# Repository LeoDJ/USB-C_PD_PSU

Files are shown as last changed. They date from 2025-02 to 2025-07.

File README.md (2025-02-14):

# USB-C PD PSU
> [!WARNING]
> This is a WIP project. It is not yet recommended to reproduce it in its current state. 

A bidirectional buck-boost DC-DC converter with the following features:
- 240W USB PD EPR (48V 5A)*
- 5-60V input
- 3.3-60V output
- 20A maximum current (theoretically, depending on the thermal solution)
- Constant-current control
- `TI BQ25758A` DC-DC controller
- `WCH CH32X035` as the USB Type-C PD controller (hopefully*)
- Protection of CC and USB data lines up to 63V (`TI TPD4S480`)
- Rough mechanical compatibility with [FranzImsch's parkside-adapter](https://github.com/FranzImsch/parkside-adapter)
- A separate-ish "HMI"/"UI" part of the PCB containing:
  - `XT30` connectors for power in/output
  - 1.47" IPS display
  - Encoder + button controls
  - 1.27mm 2x06 expansion header with a few GPIOs / RS485 for potentially communicating with BMS's, etc.
  - A second `CH32X035`
  - Separable via rotary cutting tool (no mouse bites, because of the high current connections to the XT30 plugs and to not fall into the JLCPCB "two designs" price tier)
- 50x50mm PCB size (50x23mm without the "UI" part)

\* depending on the yet-to-be-written PD firmware (and an actually functioning DC-DC converter layout :P)

You can follow the [Mastodon thread](https://chaos.social/@LeoDJ/113874922536756547) for more up-to-date progress on this project.

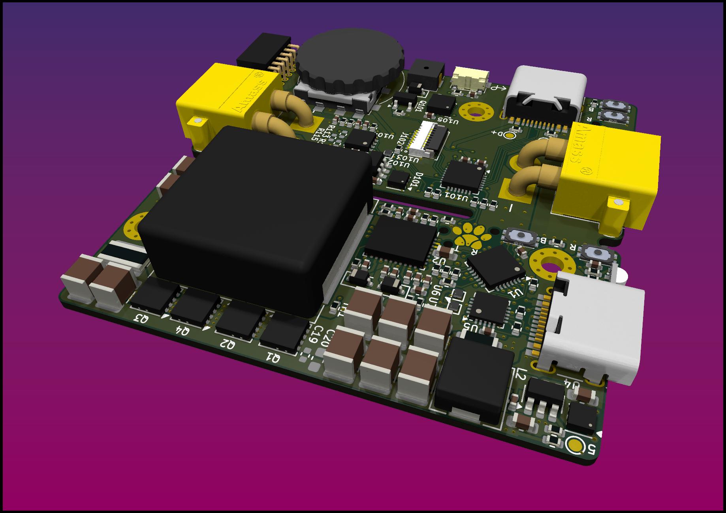
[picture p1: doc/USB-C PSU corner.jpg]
&nbsp;
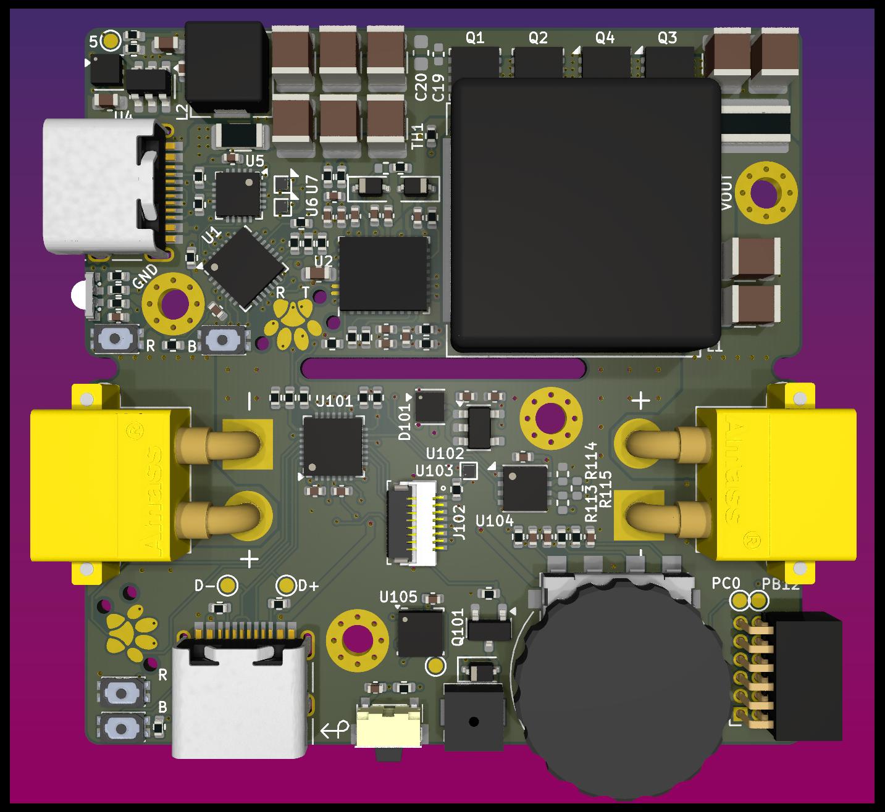
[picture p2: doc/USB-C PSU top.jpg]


## Hardware
The v1.0 PCB is designed in 8 layers, but 6 would probably suffice too. Thus inner layers 3 and 4 were designed as containing only more GND / power copper pours and can probably be left out, only leading to a reduction of a combined copper thickness from 175µm to 140µm.

### JLCPCB Ordering Settings
- Default, except:
- PCB Thickness: `1.0mm`
- Mark on PCB: `Remove Mark`
- Stencil:
  - (Stencil Side: `Top`)
  - Customized Size: `Yes - 200 x 200mm` (saves on shipping cost)

## References
- ESD-Paw symbol: [diminDDL](https://github.com/diminDDL) ([Source](https://github.com/Caraffa-git/PCB-Art/tree/main/SVG/ESD-paw))
- Paw-shaped Tag-Connect pawprint: [Paw-Connect](https://github.com/LeoDJ/Paw-Connect)

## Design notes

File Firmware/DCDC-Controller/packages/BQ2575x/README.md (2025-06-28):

# BQ2575x Library

WIP.  
Aims to be a generic library for the Texas Instruments BQ2575x-series charger / DCDC controller ICs.

Currently supported*:
- BQ25756
- BQ25758A

\* once done

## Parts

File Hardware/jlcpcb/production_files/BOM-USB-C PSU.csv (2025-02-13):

Comment | Designator | Footprint | LCSC
LIS3DH | U105 | LGA-16_3x3mm_P0.5mm_LayoutBorder3x5y | C15134
TPS22915CYFPR | U103,U6,U7 | Texas_PicoStar_BGA-4_0.758x0.758mm_Layout2x2_P0.4mm | C1849498
LMR51610XDBVR | U4 | SOT-23-6 | C20539658
Reset | SW103,SW104,SW2,SW3 | SW-SMD_4P-L3.0-W2.0-P0.85-LS3.5 | C256107
SW_Reverse | SW1 | SW-SMD_MSK12CO2 | C2681570
Expansion | J104 | PinSocket_2x06_P1.27mm_Horizontal | C2881826
SIQ-02FVS3 | SW101 | SW-SMD_SIQ-02FVS3_1 | C2925423
3.3uH 4-5mOhm | L1 | L_Chilisin_BMRF00171770 | C2976964
AO3400A | Q101 | SOT-23 | C347475
LED_ABGR | D99 | LED-ARRAY-SMD_MHS110FRGBCT | C389528
Buzzer | BZ101 | BUZ-SMD_L4.0-W4.0-P3.50-L | C391027
SW_Back | SW102 | SW-SMD_TS24CA | C393942
VIN | J4 | AMASS_XT30PW-M_1x02_P2.50mm_Horizontal | C431092
AP2112K-3.3 | U102 | SOT-23-5 | C51118
ST7789 LCD | J102 | FPC-SMD_8P-P0.50_HCTL_HC-FPC-05-10-8RLTAG | C5213730
100V 50A | Q1,Q2,Q3,Q4 | Diodes_PowerDI3333-8 | C534678
10u 100V | C18,C21,C22,C23,C24,C25,C26,C29,C30,C31 | C_1210_3225Metric | C576517
SIT3088ETK | U104 | DFN-8-1EP_3x3mm_P0.65mm_EP1.55x2.4mm | C601076
22uH <250mOhm | L2 | L_Sunlord_MWSA0503S | C718383
5m | R1 | R_1206_3216Metric | C7420039
CH32X035G8U6 | U1,U101 | QFN-28-1EP_4x4mm_P0.4mm_EP2.6x2.6mm | C7437027
B110WS | D1,D102,D2 | D_SOD-323 | C7461125
10k | TH1 | R_0402_1005Metric | C77131

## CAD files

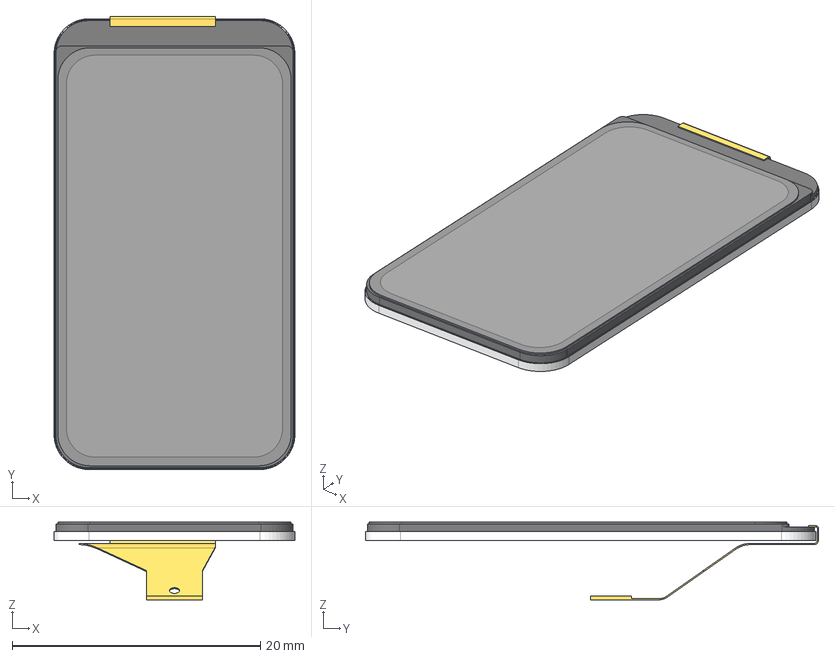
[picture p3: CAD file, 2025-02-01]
Hardware/ER-TFT1.47A1 ST7789 5mm-high bent -1.5mm.step
19.4 x 36.5 x 6.25 mm

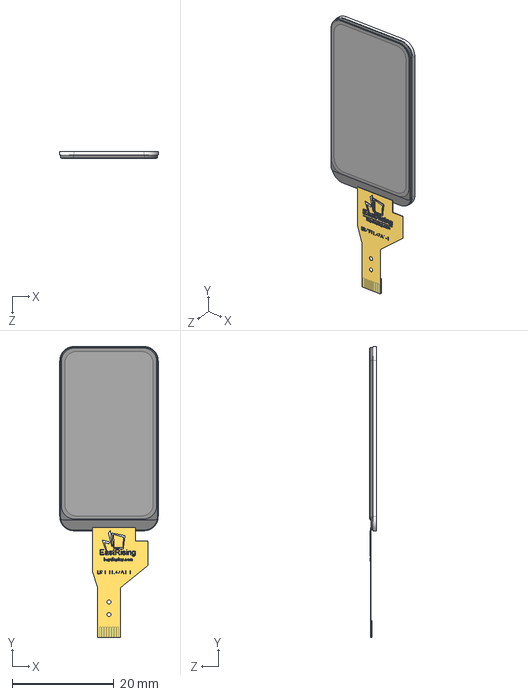
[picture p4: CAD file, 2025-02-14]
refs/ER-TFT1.47A1-1.STEP
19.4 x 57.3 x 1.46 mm

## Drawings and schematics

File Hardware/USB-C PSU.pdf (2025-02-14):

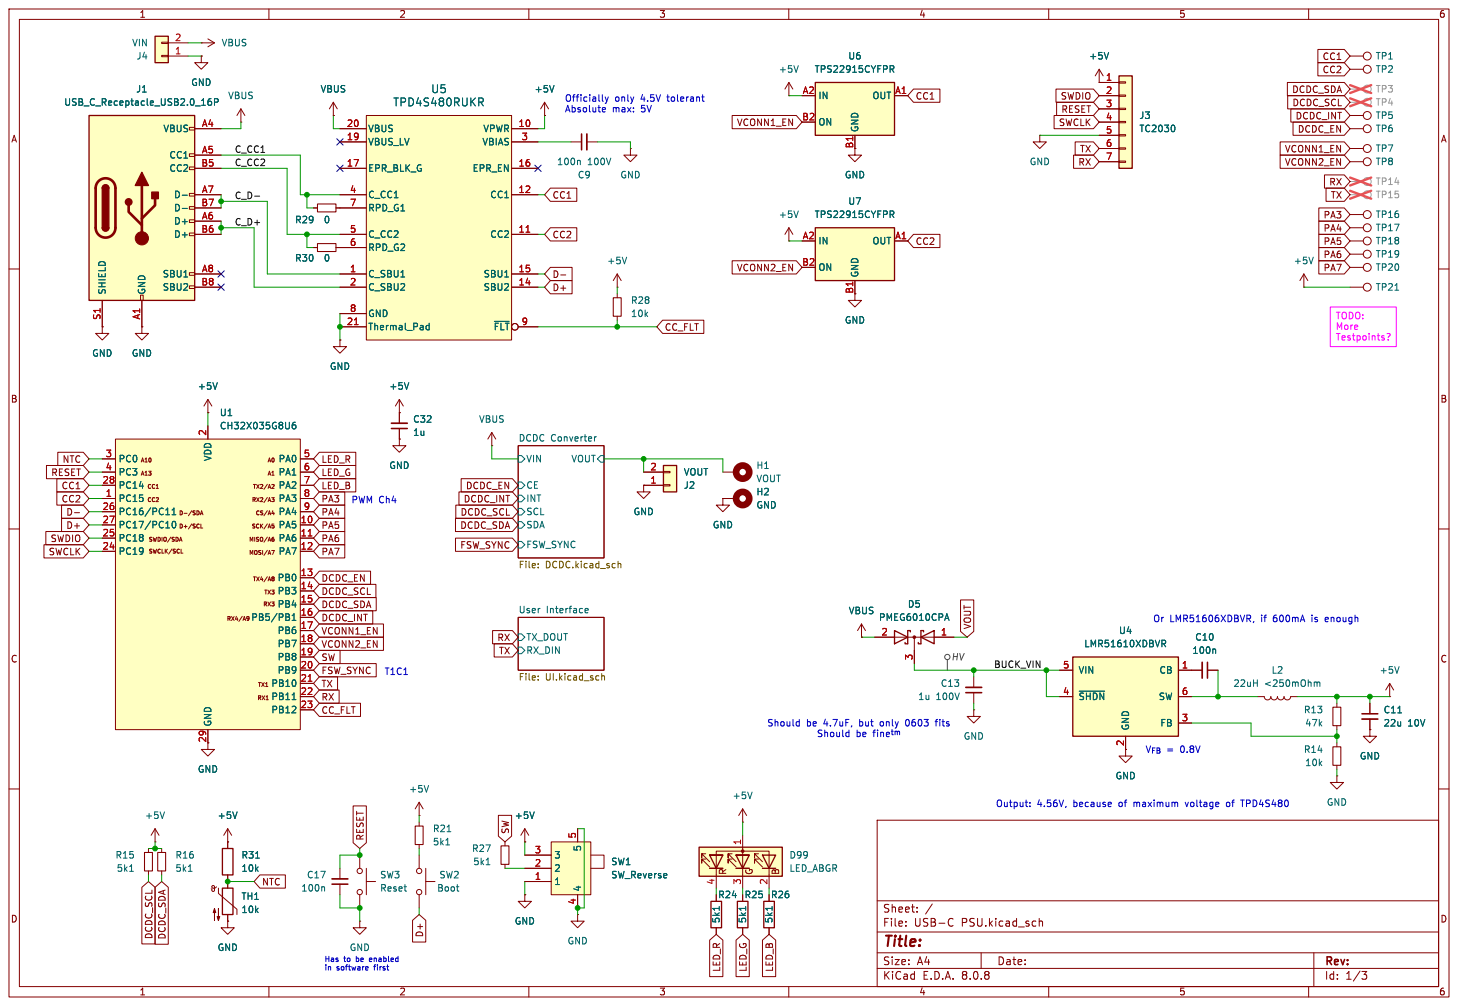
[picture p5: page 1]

2 PC15 1 PA5 10 PA6 11 PA7 12 PB0 13 PB3 14 PB4 15 PB5/PB1 16 PB6 17 PB7 18 PB8 19 PB9 20 PB10 21 PB11 22 PB12 23 PC19 24 PC18 25 PC16/PC11 26 PC17/PC10 27 PC14 28 GND 29 PC0 3 PC3 4 PA0 5 PA1 6 PA2 7 PA3 8 PA4 9 U1 CH32X035G8U6 OUT A1 IN A2 GND B1 ON B2 U7 TPS22915CYFPR

TODO: More Testpoints? +5V GND

2 FB 3 ~{SHDN} 4 VIN 5 SW 6 U4
LMR51610XDBVR
CB 1 GND

2 FB 3 ~{SHDN} 4 VIN 5 SW 6 C10

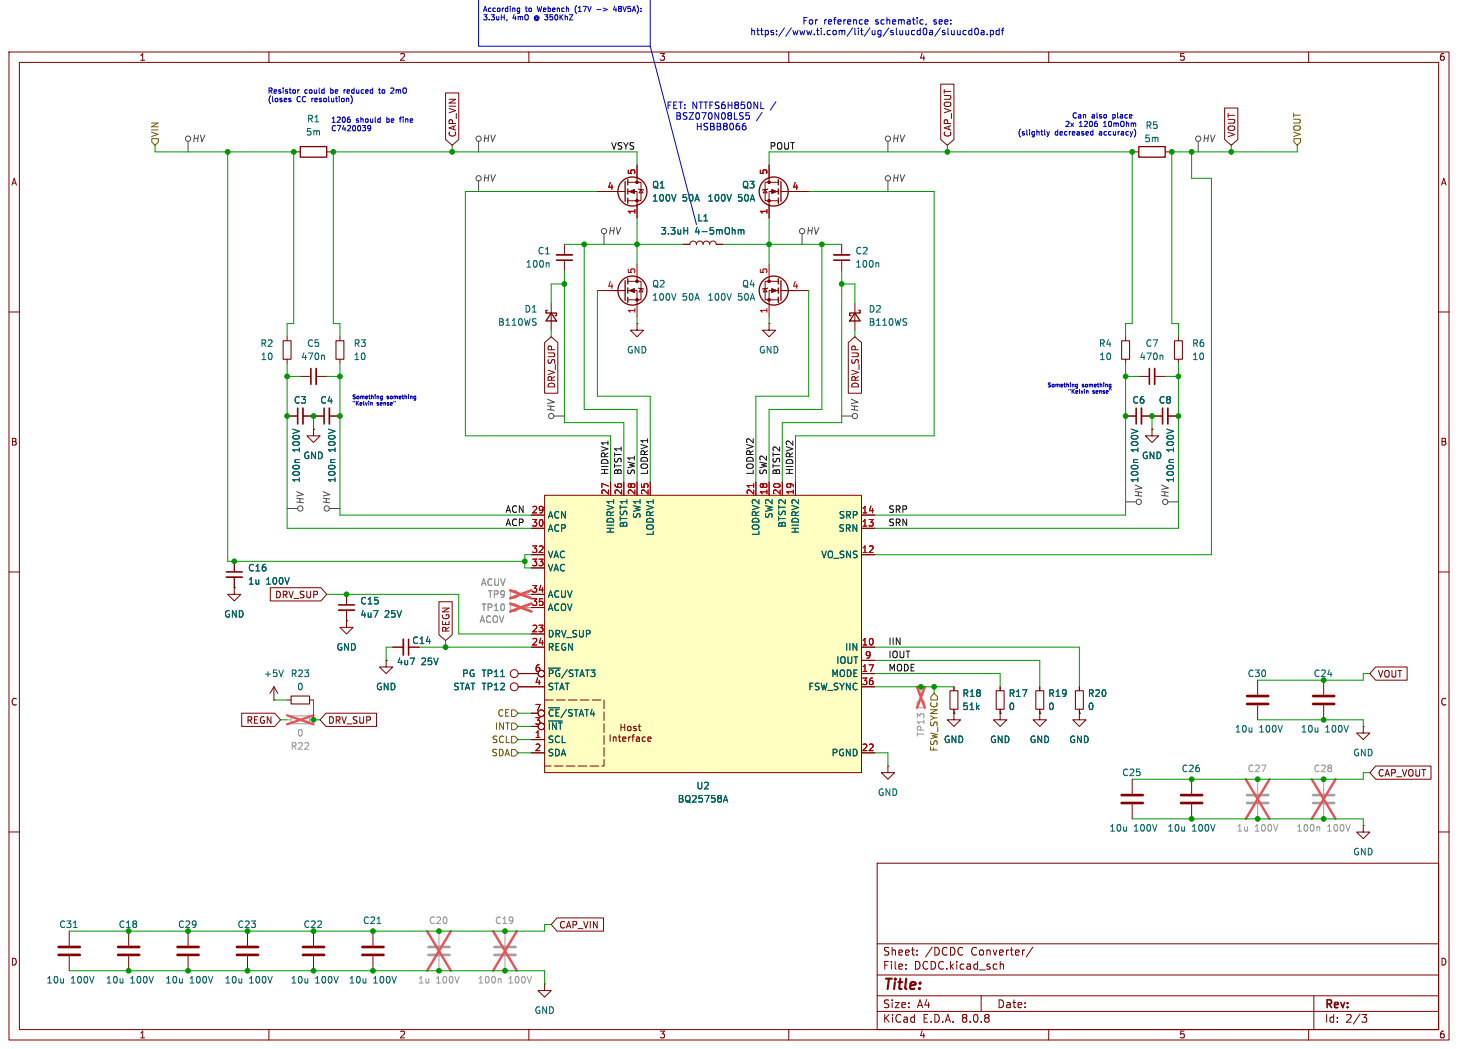
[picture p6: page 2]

Id: 2/3 Title: File: DCDC.kicad_sch Sheet: /DCDC Converter/ C16

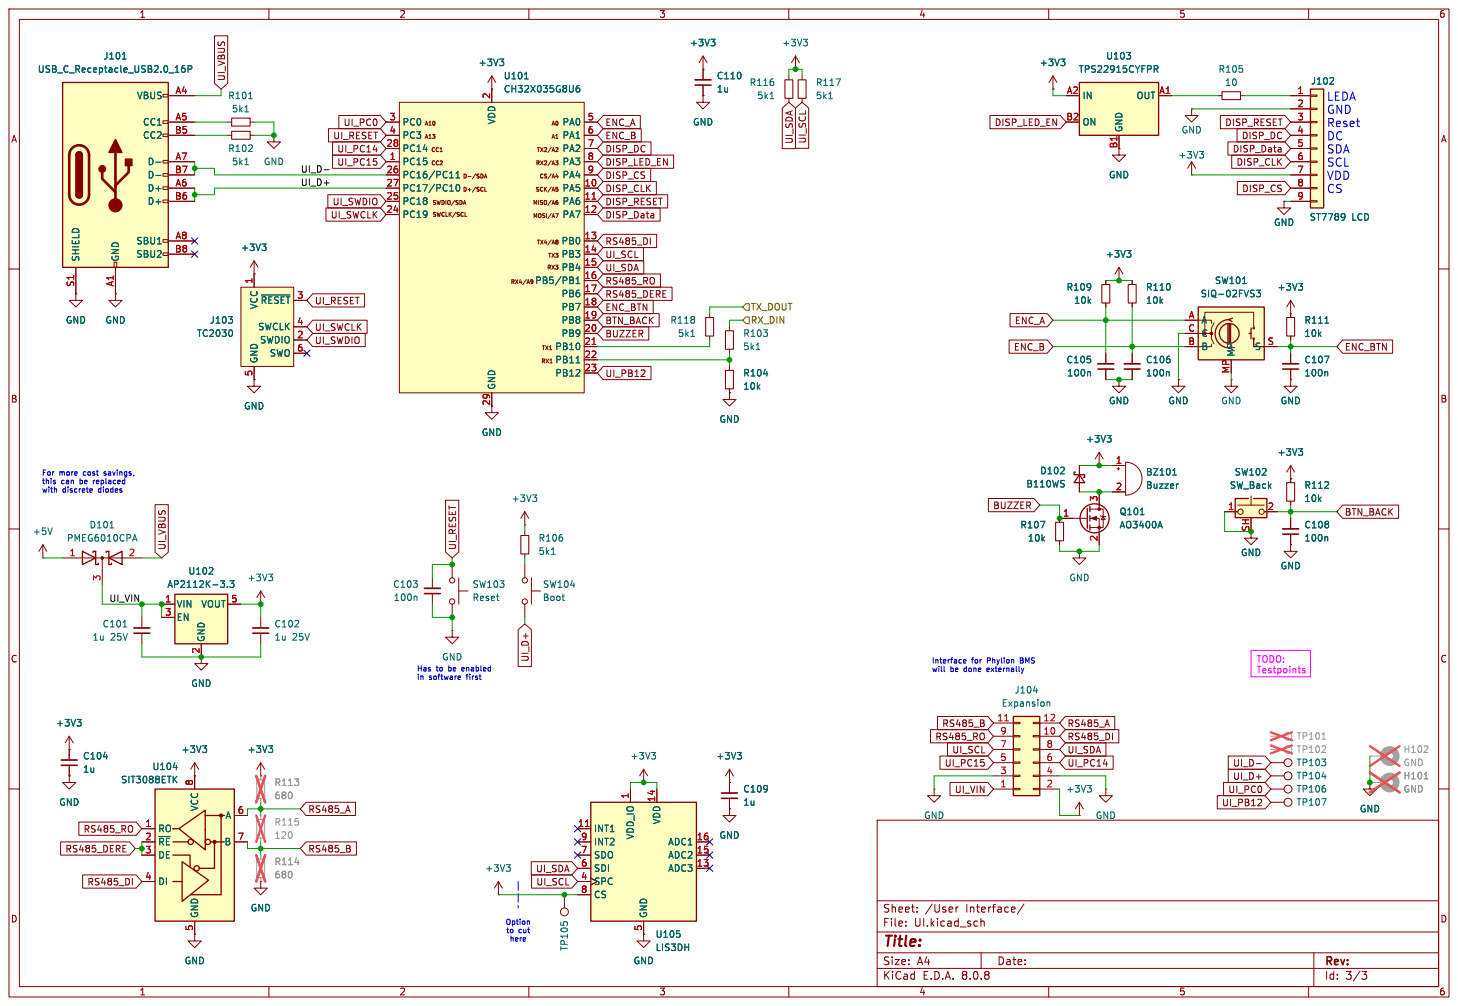
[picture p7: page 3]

1 SWDIO 2 ~{RESET}3 SWCLK 4 GND
10k GND VDD_IO

Has to be enabled

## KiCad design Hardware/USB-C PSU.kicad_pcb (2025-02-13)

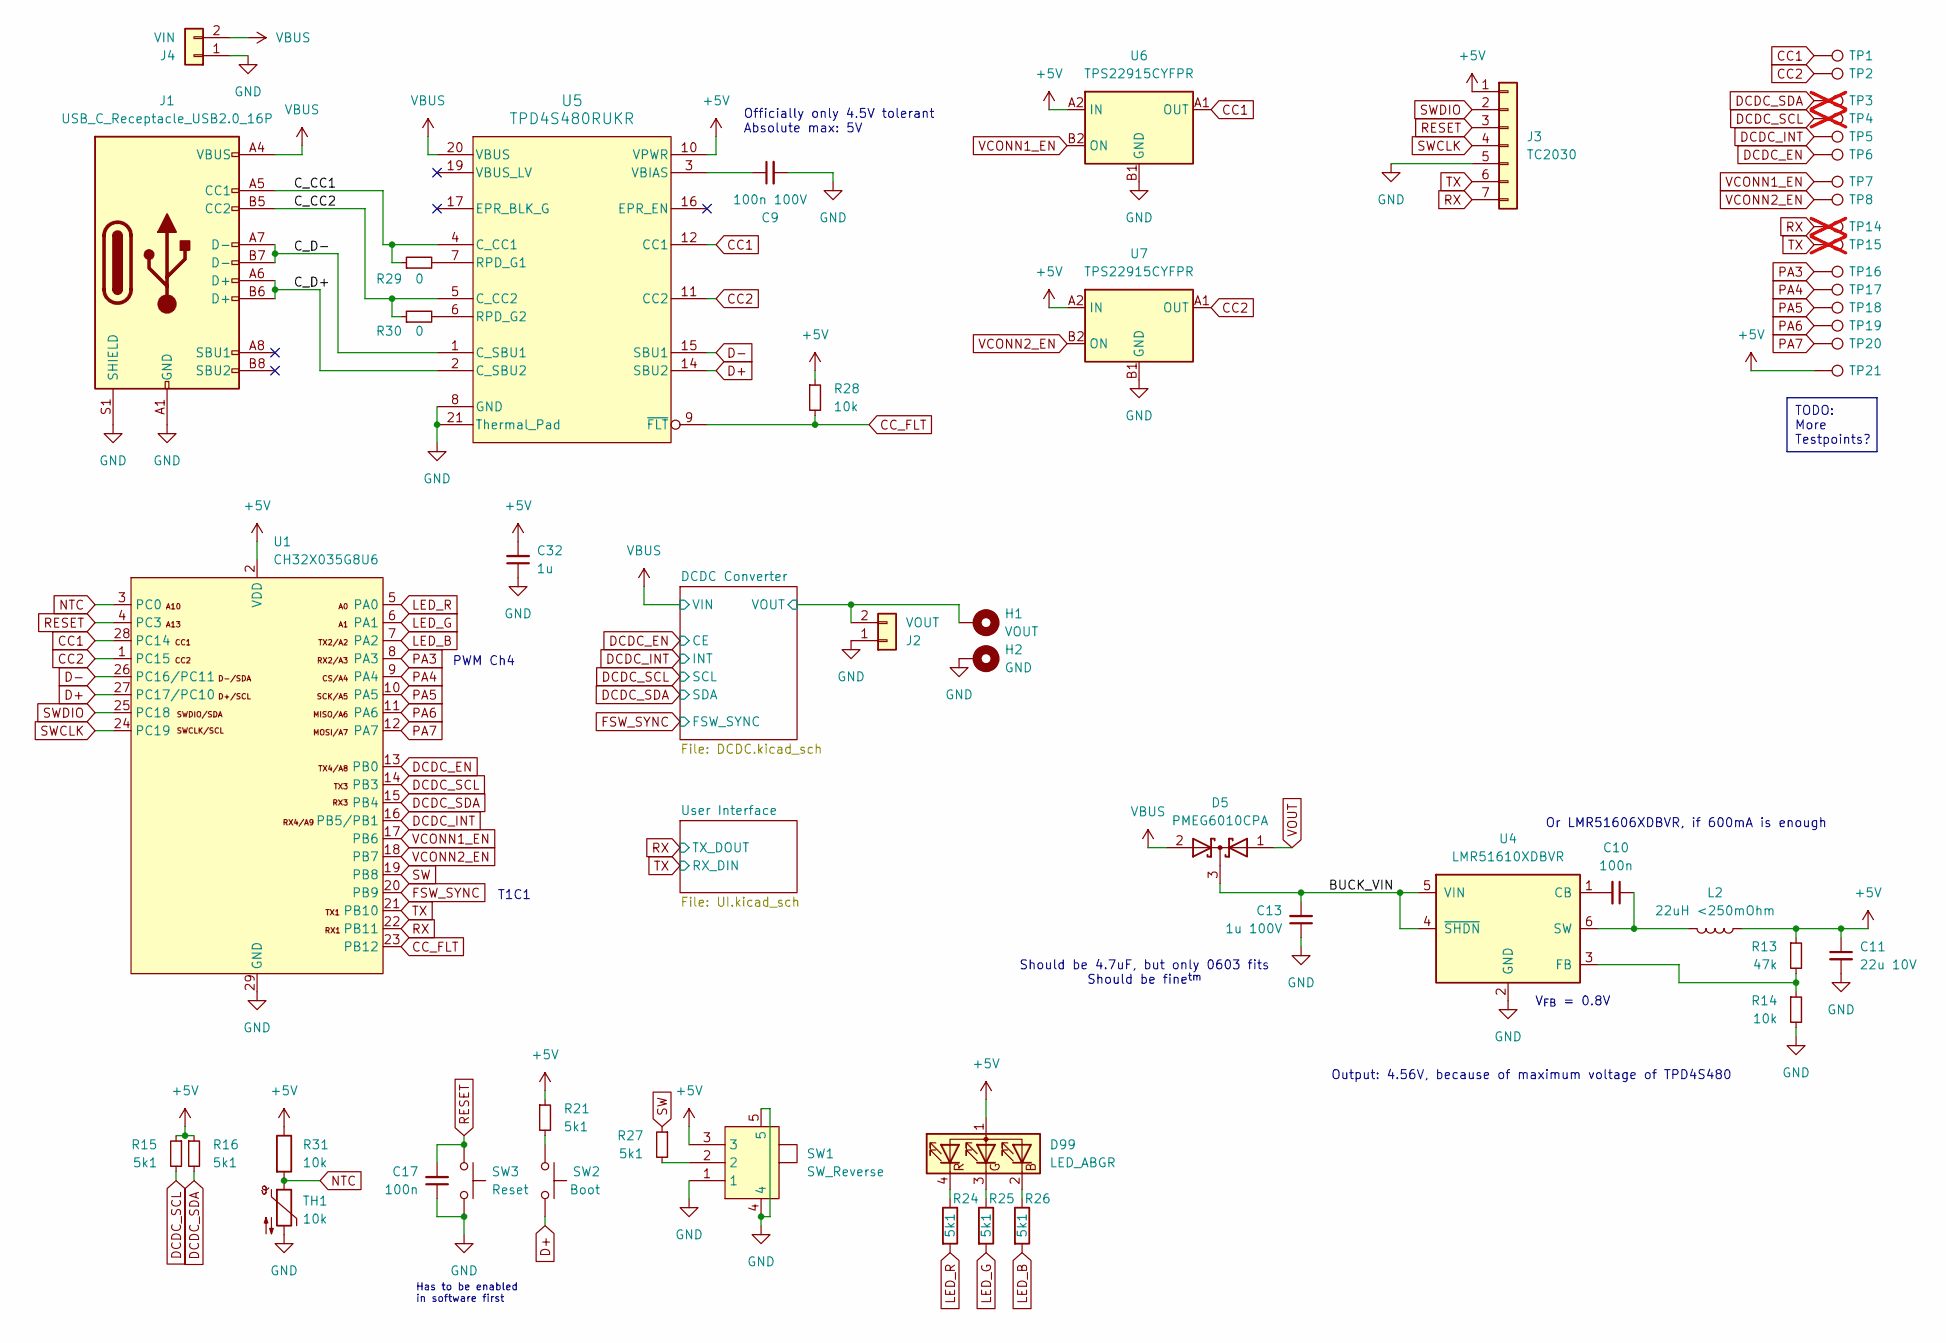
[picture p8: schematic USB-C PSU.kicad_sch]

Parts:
C9: 100n 100V; C_0402_1005Metric
C10, C17: 100n; C_0402_1005Metric
C11: 22u 10V; C_0603_1608Metric; LCSC Part C86295
C13: 1u 100V; C_0603_1608Metric
C32: 1u; C_0402_1005Metric
D5: PMEG6010CPA; HUSON-3-1EP_2x2mm_P1.3mm_EP1.1x1.6mm
D99: LED_ABGR; LED-ARRAY-SMD_MHS110FRGBCT; LCSC Part C389528
H1: VOUT; MountingHole_2.2mm_M2_Pad_Via
H2: GND; MountingHole_2.2mm_M2_Pad_Via
J1: USB_C_Receptacle_USB2.0_16P; USB_C_Receptacle_HRO_TYPE-C-31-M-12
J2: VOUT; AMASS_XT30PW-M_1x02_P2.50mm_Horizontal; LCSC Part C431092
J3: TC2030; Paw-Connect_RevB_TC2030-IDC-NL_2x03_P1.27mm_Vertical
J4: VIN; AMASS_XT30PW-M_1x02_P2.50mm_Horizontal; LCSC Part C431092
L2: 22uH <250mOhm; L_Sunlord_MWSA0503S; LCSC Part C718383
R13: 47k; R_0402_1005Metric
R14, R28, R31: 10k; R_0402_1005Metric
R15, R16, R21, R24, R25, R26, R27: 5k1; R_0402_1005Metric
R29, R30: 0; R_0402_1005Metric
SW1: SW_Reverse; SW-SMD_MSK12CO2; LCSC Part C2681570
SW2: Boot; SW-SMD_4P-L3.0-W2.0-P0.85-LS3.5; LCSC Part C256107
SW3: Reset; SW-SMD_4P-L3.0-W2.0-P0.85-LS3.5; LCSC Part C256107
TH1: 10k; R_0402_1005Metric; LCSC Part C77131
TP1, TP2, TP5, TP6, TP7, TP8, TP16, TP17, TP18, TP19, TP20, TP21: TestPoint; TestPoint_Pad_D1.0mm
TP3, TP4, TP14, TP15: TestPoint; TestPoint_Pad_D1.0mm; not fitted
U1: CH32X035G8U6; QFN-28-1EP_4x4mm_P0.4mm_EP2.6x2.6mm; LCSC Part C7437027
U4: LMR51610XDBVR; SOT-23-6; LCSC Part C20539658
U5: TPD4S480RUKR; WQFN-20-1EP_3x3mm_P0.4mm_EP1.7x1.7mm
U6, U7: TPS22915CYFPR; Texas_PicoStar_BGA-4_0.758x0.758mm_Layout2x2_P0.4mm; LCSC Part C1849498

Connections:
+5V: C11.1, C32.2, D99.1 (A), J3.1, L2.2, R13.1, R15.1, R16.1, R21.1, R28.1, R31.1, SW1.3, TP21.1, U1.2 (VDD), U5.10 (VPWR), U6.A2 (IN), U7.A2 (IN); also elsewhere on the board
/BUCK_VIN: C13.2, D5.3 (K), U4.4 (~SHDN), U4.5 (VIN)
/C_CC1: J1.A5 (CC1), R29.1, U5.4 (C_CC1)
/C_CC2: J1.B5 (CC2), R30.1, U5.5 (C_CC2)
/C_D+: J1.A6 (D+), J1.B6 (D+), U5.2 (C_SBU2)
/C_D-: J1.A7 (D-), J1.B7 (D-), U5.1 (C_SBU1)
CC1: TP1.1, U1.28 (PC14), U5.12 (CC1), U6.A1 (OUT)
CC2: TP2.1, U1.1 (PC15), U5.11 (CC2), U7.A1 (OUT)
CC_FLT: R28.2, U1.23 (PB12), U5.9 (~FLT)
D+: SW2.1, U1.27 (PC17/PC10), U5.14 (SBU2)
D-: U1.26 (PC16/PC11), U5.15 (SBU1)
DCDC_EN: TP6.1, U1.13 (PB0); also elsewhere on the board
DCDC_INT: TP5.1, U1.16 (PB5/PB1); also elsewhere on the board
DCDC_SCL: R15.2, TP4.1, U1.14 (PB3); also elsewhere on the board
DCDC_SDA: R16.2, TP3.1, U1.15 (PB4); also elsewhere on the board
FSW_SYNC: U1.20 (PB9); also elsewhere on the board
GND: C9.2, C11.2, C13.1, C17.1, C32.1, H2.1, J1.A1 (GND), J1.A12 (GND), J1.B1 (GND), J1.B12 (GND), J1.S1 (SHIELD), J2.1, J3.5, J4.1, R14.2, SW1.1, SW1.4, SW1.5, SW3.2, TH1.2, U1.29 (GND), U4.2 (GND), U5.8 (GND), U5.13 (GND), U5.18 (GND), U5.21 (Thermal_Pad), U6.B1 (GND), U7.B1 (GND); also elsewhere on the board
LED_B: R26.2, U1.7 (PA2)
LED_G: R25.2, U1.6 (PA1)
LED_R: R24.2, U1.5 (PA0)
NTC: R31.2, TH1.1, U1.3 (PC0)
unnamed: D99.2 (BK), R26.1
unnamed: D99.3 (GK), R25.1
unnamed: D99.4 (RK), R24.1
unnamed: R21.2, SW2.2
unnamed: R27.2, SW1.2
unnamed: C10.2, U4.1 (CB)
unnamed: R13.2, R14.1, U4.3 (FB)
unnamed: C10.1, L2.1, U4.6 (SW)
unnamed: R29.2, U5.7 (RPD_G1)
unnamed: R30.2, U5.6 (RPD_G2)
unnamed: C9.1, U5.3 (VBIAS)
PA3: TP16.1, U1.8 (PA3)
PA4: TP17.1, U1.9 (PA4)
PA5: TP18.1, U1.10 (PA5)
PA6: TP19.1, U1.11 (PA6)
PA7: TP20.1, U1.12 (PA7)
RESET: C17.2, J3.3, SW3.1, U1.4 (PC3)
RX: J3.7, TP14.1, U1.22 (PB11); also elsewhere on the board
SW: R27.1, U1.19 (PB8)
SWCLK: J3.4, U1.24 (PC19)
SWDIO: J3.2, U1.25 (PC18)
TX: J3.6, TP15.1, U1.21 (PB10); also elsewhere on the board
VBUS: D5.2 (A), J1.A4 (VBUS), J1.A9 (VBUS), J1.B4 (VBUS), J1.B9 (VBUS), J4.2, U5.20 (VBUS); also elsewhere on the board
VCONN1_EN: TP7.1, U1.17 (PB6), U6.B2 (ON)
VCONN2_EN: TP8.1, U1.18 (PB7), U7.B2 (ON)
VOUT: D5.1 (A), H1.1, J2.2; also elsewhere on the board

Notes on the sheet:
TODO: More Testpoints?
V_{FB} = 0.8V
PWM Ch4
T1C1
Has to be enabled in software first
Officially only 4.5V tolerant Absolute max: 5V
Should be 4.7uF, but only 0603 fits Should be fine^{tm}
Output: 4.56V, because of maximum voltage of TPD4S480
Or LMR51606XDBVR, if 600mA is enough

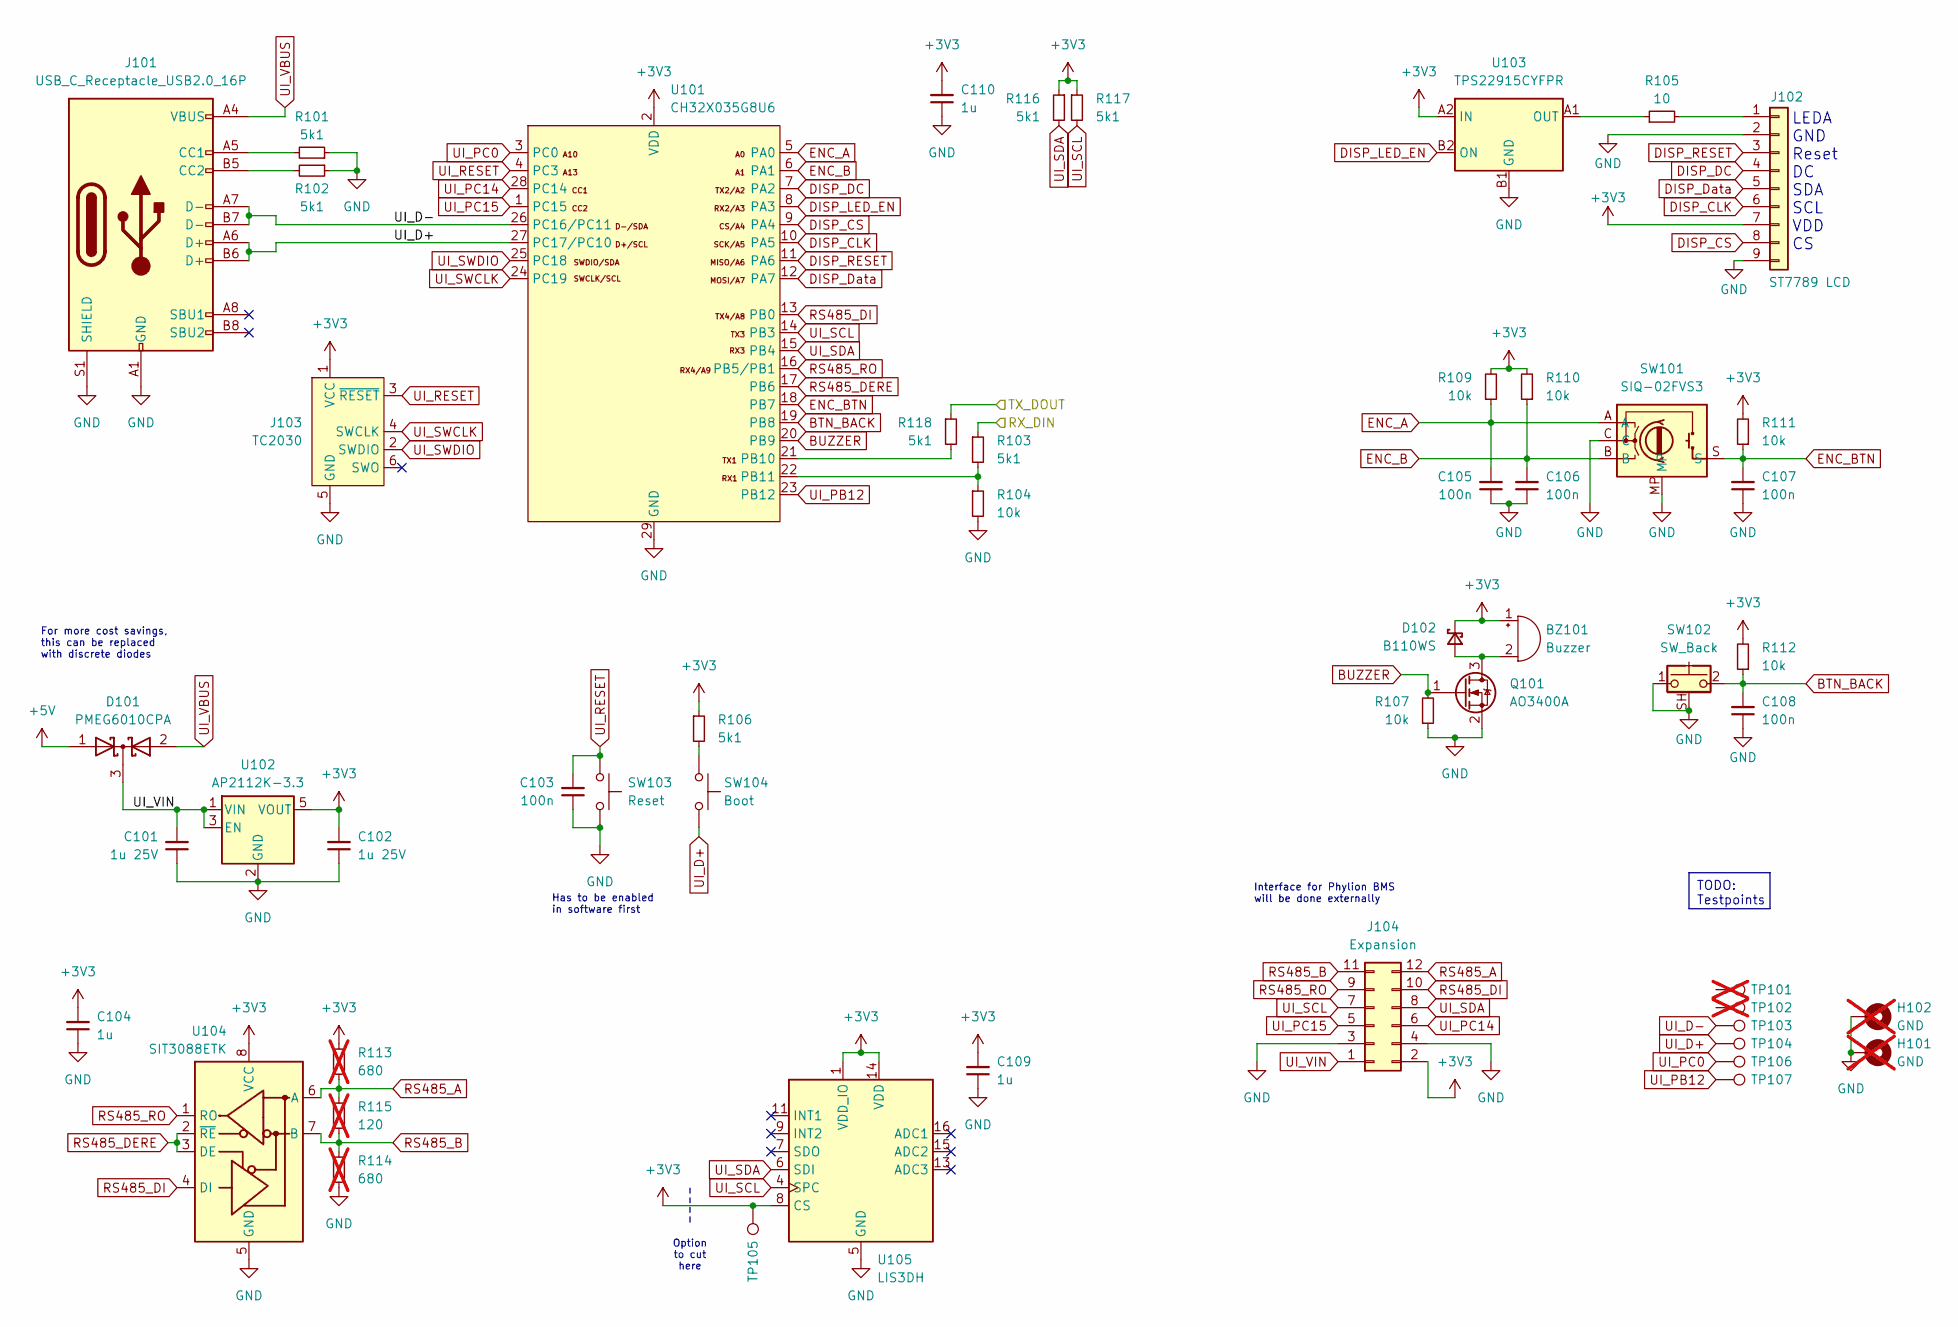
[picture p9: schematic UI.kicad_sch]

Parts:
BZ101: Buzzer; BUZ-SMD_L4.0-W4.0-P3.50-L; LCSC Part C391027
C101, C102: 1u 25V; C_0402_1005Metric; LCSC Part C52923
C103, C105, C106, C107, C108: 100n; C_0402_1005Metric
C104, C109, C110: 1u; C_0402_1005Metric
D101: PMEG6010CPA; HUSON-3-1EP_2x2mm_P1.3mm_EP1.1x1.6mm
D102: B110WS; D_SOD-323; LCSC Part C7461125
H101, H102: GND; MountingHole_2.2mm_M2_Pad_Via; not fitted
J101: USB_C_Receptacle_USB2.0_16P; USB_C_Receptacle_HRO_TYPE-C-31-M-12
J102: ST7789 LCD; FPC-SMD_8P-P0.50_HCTL_HC-FPC-05-10-8RLTAG; LCSC Part C5213730
J103: TC2030; Paw-Connect_RevB_TC2030-IDC-NL_2x03_P1.27mm_Vertical
J104: Expansion; PinSocket_2x06_P1.27mm_Horizontal; LCSC Part C2881826
Q101: AO3400A; SOT-23; LCSC Part C347475
R101, R102, R103, R106, R116, R117, R118: 5k1; R_0402_1005Metric
R104, R107, R109, R110, R111, R112: 10k; R_0402_1005Metric
R105: 10; R_0402_1005Metric
R113, R114: 680; R_0402_1005Metric; not fitted
R115: 120; R_0402_1005Metric; not fitted
SW101: SIQ-02FVS3; SW-SMD_SIQ-02FVS3_1; LCSC Part C2925423
SW102: SW_Back; SW-SMD_TS24CA; LCSC Part C393942
SW103: Reset; SW-SMD_4P-L3.0-W2.0-P0.85-LS3.5; LCSC Part C256107
SW104: Boot; SW-SMD_4P-L3.0-W2.0-P0.85-LS3.5; LCSC Part C256107
TP101, TP102: TestPoint; TestPoint_Pad_D1.0mm; not fitted
TP103: D-; TestPoint_Pad_D1.0mm
TP104: D+; TestPoint_Pad_D1.0mm
TP105: TestPoint; TestPoint_Pad_D1.0mm
TP106: PC0; TestPoint_Pad_D1.0mm
TP107: PB12; TestPoint_Pad_D1.0mm
U101: CH32X035G8U6; QFN-28-1EP_4x4mm_P0.4mm_EP2.6x2.6mm; LCSC Part C7437027
U102: AP2112K-3.3; SOT-23-5; LCSC Part C51118
U103: TPS22915CYFPR; Texas_PicoStar_BGA-4_0.758x0.758mm_Layout2x2_P0.4mm; LCSC Part C1849498
U104: SIT3088ETK; DFN-8-1EP_3x3mm_P0.65mm_EP1.55x2.4mm; LCSC Part C601076
U105: LIS3DH; LGA-16_3x3mm_P0.5mm_LayoutBorder3x5y; LCSC Part C15134

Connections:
+3V3: BZ101.1 (+), C102.2, C104.2, C109.2, C110.2, D102.1 (K), J102.7, J103.1 (VCC), J104.2, R106.1, R109.2, R110.2, R111.2, R112.2, R113.2, R116.1, R117.1, TP105.1, U101.2 (VDD), U102.5 (VOUT), U103.A2 (IN), U104.8 (VCC), U105.1 (VDD_IO), U105.8 (CS), U105.14 (VDD)
+5V: D101.1 (A); also elsewhere on the board
BTN_BACK: C108.2, R112.1, SW102.2, U101.19 (PB8)
BUZZER: Q101.1 (G), R107.2, U101.20 (PB9)
DISP_CLK: J102.6, U101.10 (PA5)
DISP_CS: J102.8, U101.9 (PA4)
DISP_DC: J102.4, U101.7 (PA2)
DISP_Data: J102.5, U101.12 (PA7)
DISP_LED_EN: U101.8 (PA3), U103.B2 (ON)
DISP_RESET: J102.3, U101.11 (PA6)
ENC_A: C105.2, R109.1, SW101.A, U101.5 (PA0)
ENC_B: C106.2, R110.1, SW101.B, U101.6 (PA1)
ENC_BTN: C107.2, R111.1, SW101.S, U101.18 (PB7)
GND: C101.1, C102.1, C103.1, C104.1, C105.1, C106.1, C107.1, C108.1, C109.1, C110.1, H101.1, H102.1, J101.A1 (GND), J101.A12 (GND), J101.B1 (GND), J101.B12 (GND), J101.S1 (SHIELD), J102.2, J102.9, J103.5 (GND), J104.3, J104.4, Q101.2 (S), R101.1, R102.1, R104.2, R107.1, R114.1, SW101.C, SW101.MP, SW102.1, SW102.SH (B), SW103.2, U101.29 (GND), U102.2 (GND), U103.B1 (GND), U104.5 (GND), U104.9 (GND), U105.5 (GND), U105.10 (GND), U105.12 (GND); also elsewhere on the board
unnamed: BZ101.2 (-), D102.2 (A), Q101.3 (D)
unnamed: J101.A5 (CC1), R101.2
unnamed: J101.B5 (CC2), R102.2
unnamed: J102.1, R105.2
unnamed: R106.2, SW104.2
unnamed: R118.2, U101.21 (PB10)
unnamed: R103.2, R104.1, U101.22 (PB11)
unnamed: R105.1, U103.A1 (OUT)
RS485_A: J104.12, R113.1, R115.2, U104.6 (A)
RS485_B: J104.11, R114.2, R115.1, U104.7 (B)
RS485_DERE: U101.17 (PB6), U104.2 (~RE), U104.3 (DE)
RS485_DI: J104.10, U101.13 (PB0), U104.4 (DI)
RS485_RO: J104.9, U101.16 (PB5/PB1), U104.1 (RO)
RX: R118.1; also elsewhere on the board
TX: R103.1; also elsewhere on the board
UI_D+: J101.A6 (D+), J101.B6 (D+), SW104.1, TP104.1, U101.27 (PC17/PC10)
UI_D-: J101.A7 (D-), J101.B7 (D-), TP103.1, U101.26 (PC16/PC11)
UI_PB12: TP107.1, U101.23 (PB12)
UI_PC0: TP106.1, U101.3 (PC0)
UI_PC14: J104.6, U101.28 (PC14)
UI_PC15: J104.5, U101.1 (PC15)
UI_RESET: C103.2, J103.3 (~RESET), SW103.1, U101.4 (PC3)
UI_SCL: J104.7, R117.2, U101.14 (PB3), U105.4 (SPC)
UI_SDA: J104.8, R116.2, U101.15 (PB4), U105.6 (SDI)
UI_SWCLK: J103.4 (SWCLK), U101.24 (PC19)
UI_SWDIO: J103.2 (SWDIO), U101.25 (PC18)
UI_VBUS: D101.2 (A), J101.A4 (VBUS), J101.A9 (VBUS), J101.B4 (VBUS), J101.B9 (VBUS)
UI_VIN: C101.2, D101.3 (K), J104.1, U102.1 (VIN), U102.3 (EN)

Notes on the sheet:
TODO: Testpoints
Interface for Phylion BMS will be done externally
Has to be enabled in software first
Option to cut here
LEDA GND Reset DC SDA SCL VDD CS
For more cost savings, this can be replaced with discrete diodes

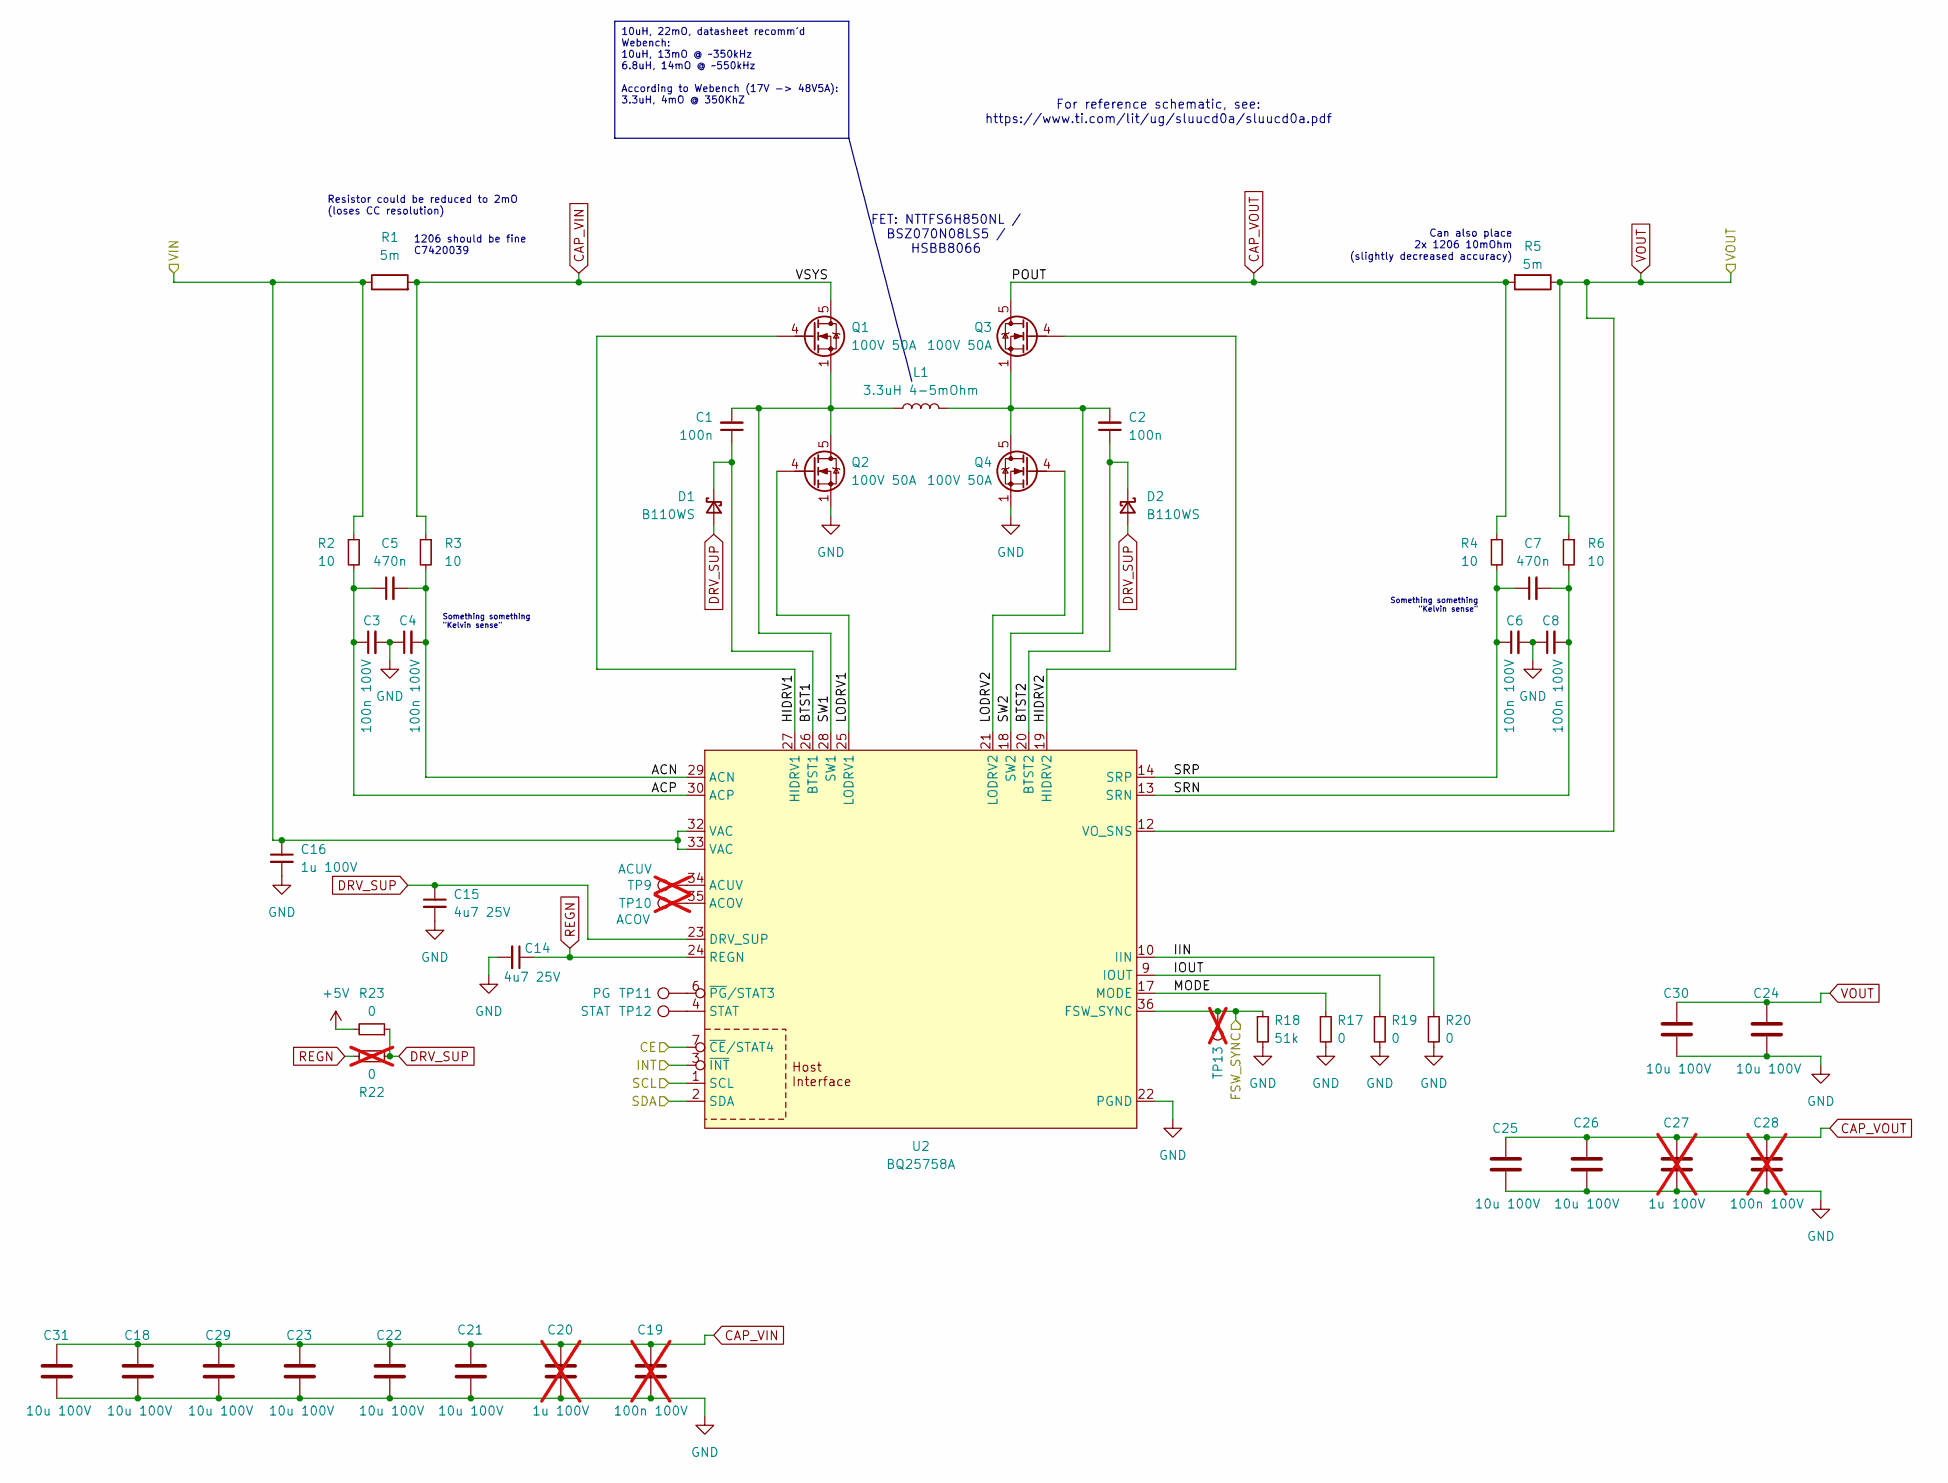
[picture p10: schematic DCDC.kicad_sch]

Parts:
C1, C2: 100n; C_0402_1005Metric
C3, C4, C6, C8: 100n 100V; C_0402_1005Metric
C5, C7: 470n; C_0402_1005Metric
C14, C15: 4u7 25V; C_0402_1005Metric
C16: 1u 100V; C_0603_1608Metric
C18, C21, C22, C23, C24, C25, C26, C29, C30, C31: 10u 100V; C_1210_3225Metric; LCSC Part C576517
C19, C28: 100n 100V; C_0402_1005Metric; not fitted
C20, C27: 1u 100V; C_0603_1608Metric; not fitted
D1, D2: B110WS; D_SOD-323; LCSC Part C7461125
L1: 3.3uH 4-5mOhm; L_Chilisin_BMRF00171770; LCSC Part C2976964
Q1, Q2, Q3, Q4: 100V 50A; Diodes_PowerDI3333-8; LCSC Part C534678
R1: 5m; R_1206_3216Metric; LCSC Part C7420039
R2, R3, R4, R6: 10; R_0402_1005Metric
R5: 5m; R_1020_2550Metric_Pad1.33x5.20mm_HandSolder; LCSC Part C843878
R17, R19, R20, R23: 0; R_0402_1005Metric
R18: 51k; R_0402_1005Metric
R22: 0; R_0402_1005Metric; not fitted
TP9: ACUV; TestPoint_Pad_D1.0mm; not fitted
TP10: ACOV; TestPoint_Pad_D1.0mm; not fitted
TP11: PG; TestPoint_Pad_D1.0mm
TP12: STAT; TestPoint_Pad_D1.0mm
TP13: FSW_SYNC; TestPoint_Pad_D1.0mm; not fitted
U2: BQ25758A; Texas_RRV0036A_VQFN-36-1EP_5x6mm_P0.5mm_EP3.6x4.6mm_Thermal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

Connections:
+5V: R23.2; also elsewhere on the board
/DCDC Converter/ACN: C4.2, C5.2, R3.2, U2.29 (ACN)
/DCDC Converter/ACP: C3.1, C5.1, R2.2, U2.30 (ACP)
/DCDC Converter/BTST1: C1.1, D1.1 (K), U2.26 (BTST1)
/DCDC Converter/BTST2: C2.1, D2.1 (K), U2.20 (BTST2)
/DCDC Converter/HIDRV1: Q1.4 (G), U2.27 (HIDRV1)
/DCDC Converter/HIDRV2: Q3.4 (G), U2.19 (HIDRV2)
/DCDC Converter/IIN: R20.1, U2.10 (IIN)
/DCDC Converter/IOUT: R19.1, U2.9 (IOUT)
/DCDC Converter/LODRV1: Q2.4 (G), U2.25 (LODRV1)
/DCDC Converter/LODRV2: Q4.4 (G), U2.21 (LODRV2)
/DCDC Converter/MODE: R17.1, U2.17 (MODE)
/DCDC Converter/SRN: C7.2, C8.2, R6.2, U2.13 (SRN)
/DCDC Converter/SRP: C6.1, C7.1, R4.2, U2.14 (SRP)
/DCDC Converter/SW1: C1.2, L1.1, Q1.1 (S), Q1.2 (S), Q1.3 (S), Q2.5 (D), Q2.6 (D), Q2.7 (D), Q2.8 (D), U2.28 (SW1)
/DCDC Converter/SW2: C2.2, L1.2, Q3.1 (S), Q3.2 (S), Q3.3 (S), Q4.5 (D), Q4.6 (D), Q4.7 (D), Q4.8 (D), U2.18 (SW2)
CAP_VIN: C18.1, C19.1, C20.1, C21.1, C22.1, C23.1, C29.1, C31.1, Q1.5 (D), Q1.6 (D), Q1.7 (D), Q1.8 (D), R1.2, R3.1
CAP_VOUT: C25.1, C26.1, C27.1, C28.1, Q3.5 (D), Q3.6 (D), Q3.7 (D), Q3.8 (D), R4.1, R5.2
DCDC_EN: U2.7 (~CE/STAT4); also elsewhere on the board
DCDC_INT: U2.3 (~INT); also elsewhere on the board
DCDC_SCL: U2.1 (SCL); also elsewhere on the board
DCDC_SDA: U2.2 (SDA); also elsewhere on the board
DRV_SUP: C15.1, D1.2 (A), D2.2 (A), R22.1, R23.1, U2.23 (DRV_SUP)
FSW_SYNC: R18.1, TP13.1, U2.36 (FSW_SYNC); also elsewhere on the board
GND: C3.2, C4.1, C6.2, C8.1, C14.2, C15.2, C16.2, C18.2, C19.2, C20.2, C21.2, C22.2, C23.2, C24.2, C25.2, C26.2, C27.2, C28.2, C29.2, C30.2, C31.2, Q2.1 (S), Q2.2 (S), Q2.3 (S), Q4.1 (S), Q4.2 (S), Q4.3 (S), R17.2, R18.2, R19.2, R20.2, U2.22 (PGND), U2.37 (PAD); also elsewhere on the board
unnamed: TP10.1, U2.35 (ACOV)
unnamed: TP9.1, U2.34 (ACUV)
unnamed: TP12.1, U2.4 (STAT)
unnamed: TP11.1, U2.6 (~PG/STAT3)
REGN: C14.1, R22.2, U2.24 (REGN)
VBUS: C16.1, R1.1, R2.1, U2.32 (VAC), U2.33 (VAC); also elsewhere on the board
VOUT: C24.1, C30.1, R5.1, R6.1, U2.12 (VO_SNS); also elsewhere on the board

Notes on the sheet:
10uH, 22mO, datasheet recomm'd Webench: 10uH, 13mO @ ~350kHz 6.8uH, 14mO @ ~550kHz According to Webench (17V -> 48V5A): 3.3uH, 4mO @ 350KhZ
FET: NTTFS6H850NL / BSZ070N08LS5 / HSBB8066
Something something "Kelvin sense"
1206 should be fine C7420039
Resistor could be reduced to 2mO (loses CC resolution)
Can also place 2x 1206 10mOhm (slightly decreased accuracy)
For reference schematic, see: https://www.ti.com/lit/ug/sluucd0a/sluucd0a.pdf

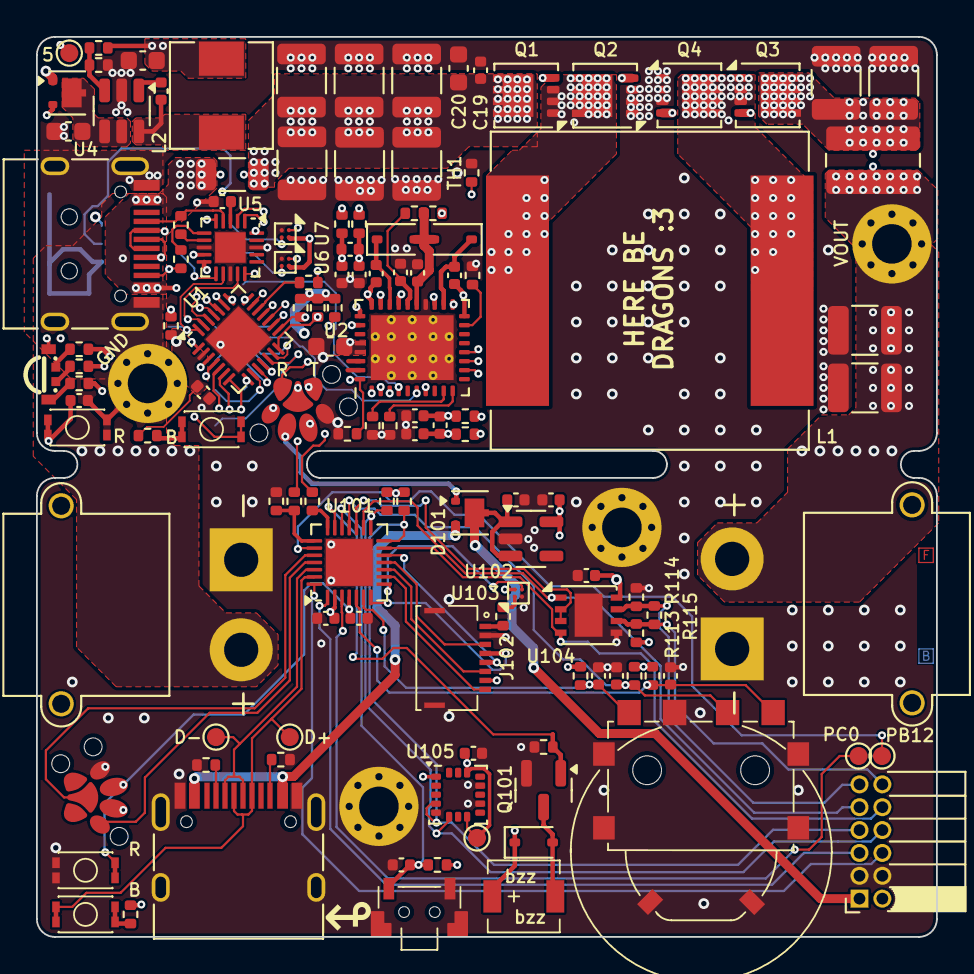
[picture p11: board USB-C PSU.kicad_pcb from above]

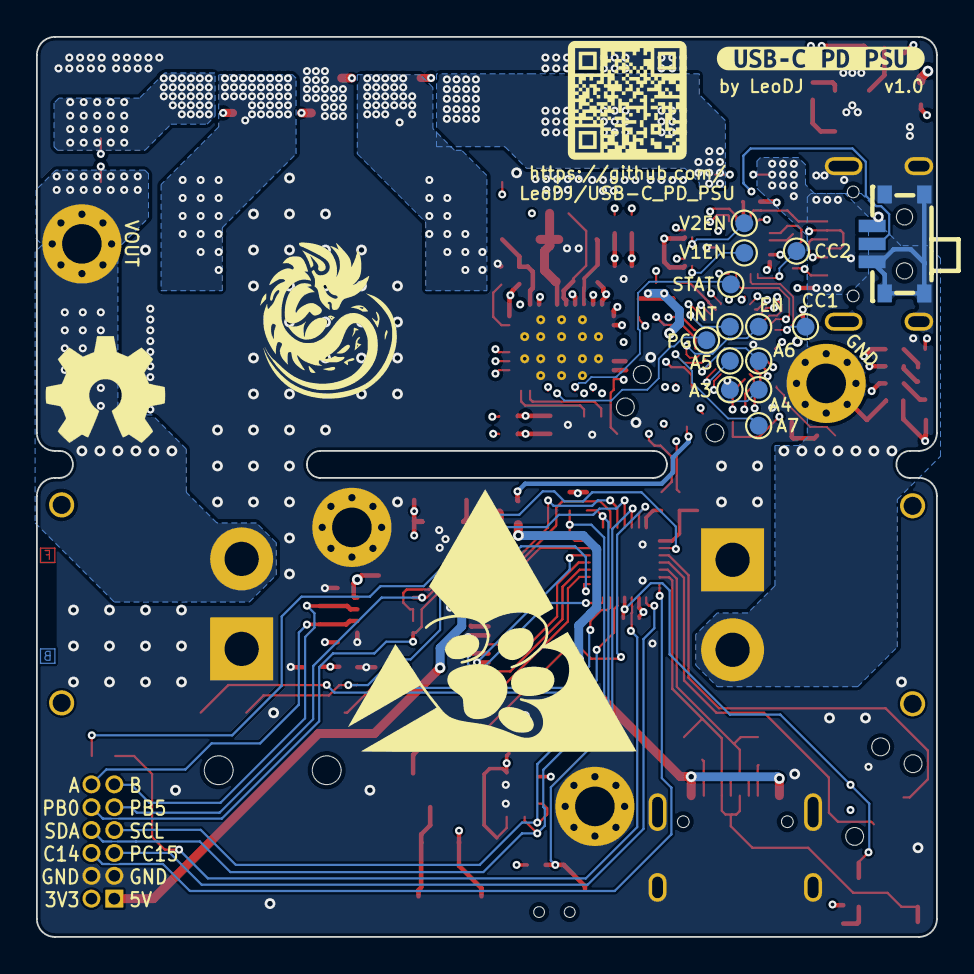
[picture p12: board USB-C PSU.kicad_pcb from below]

Board: 8 copper layers, 50.0 x 50.0 mm, 146 parts (15 on the bottom side), 106 nets.

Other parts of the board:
kibuzzard-67A54591: G***; kibuzzard-67A54591

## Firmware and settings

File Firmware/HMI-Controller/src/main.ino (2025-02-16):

/*
 Adapted from the Adafruit and Xark's PDQ graphicstest sketch.

 See end of file for original header text and MIT license info.
 
 This sketch uses the GLCD font only.

 Make sure all the display driver and pin connections are correct by
 editing the User_Setup.h file in the TFT_eSPI library folder.

 #########################################################################
 ###### DON'T FORGET TO UPDATE THE User_Setup.h FILE IN THE LIBRARY ######
 #########################################################################
 */

#include "SPI.h"
#include "TFT_eSPI.h"
#include "TFT_eSPI_CH32.hpp"

// Use hardware SPI
TFT_eSPI tft = TFT_eSPI();

unsigned long total = 0;
unsigned long tn = 0;
void setup() {
  Serial.begin(115200);
  while (!Serial);
  Serial.println(""); Serial.println("");
  Serial.println("Bodmer's TFT_eSPI library Test!"); 
 
  tft.init();
  tft.fillScreen(TFT_BLACK);
}

void loopp() {
		tft.fillRect(0, 0, 8, tft.height(), TFT_WHITE);
    delay(1);
		tft.fillRect(0, 0, 8, tft.height(), TFT_BLACK);
    delay(1);
}

void loop(void)
{

	Serial.println(F("Benchmark                Time (microseconds)"));

	uint32_t usecHaD = testHaD();
	Serial.print(F("HaD pushColor            "));
	Serial.println(usecHaD);
	delay(100);

	uint32_t usecFillScreen = testFillScreen();
	Serial.print(F("Screen fill              "));
	Serial.println(usecFillScreen);
	delay(100);

	uint32_t usecText = testText();
	Serial.print(F("Text                     "));
	Serial.println(usecText);
	delay(100);

	uint32_t usecPixels = testPixels();
	Serial.print(F("Pixels                   "));
	Serial.println(usecPixels);
	delay(100);

	uint32_t usecLines = testLines(TFT_BLUE);
	Serial.print(F("Lines                    "));
	Serial.println(usecLines);
	delay(100);

	uint32_t usecFastLines = testFastLines(TFT_RED, TFT_BLUE);
	Serial.print(F("Horiz/Vert Lines         "));
	Serial.println(usecFastLines);
	delay(100);

	uint32_t usecRects = testRects(TFT_GREEN);
	Serial.print(F("Rectangles (outline)     "));
	Serial.println(usecRects);
	delay(100);

	uint32_t usecFilledRects = testFilledRects(TFT_YELLOW, TFT_MAGENTA);
	Serial.print(F("Rectangles (filled)      "));
	Serial.println(usecFilledRects);
	delay(100);

	uint32_t usecFilledCircles = testFilledCircles(10, TFT_MAGENTA);
	Serial.print(F("Circles (filled)         "));
	Serial.println(usecFilledCircles);
	delay(100);

	uint32_t usecCircles = testCircles(10, TFT_WHITE);
	Serial.print(F("Circles (outline)        "));
	Serial.println(usecCircles);
	delay(100);

	uint32_t usecTriangles = testTriangles();
	Serial.print(F("Triangles (outline)      "));
	Serial.println(usecTriangles);
	delay(100);

	uint32_t usecFilledTrangles = testFilledTriangles();
	Serial.print(F("Triangles (filled)       "));
	Serial.println(usecFilledTrangles);
	delay(100);

	uint32_t usecRoundRects = testRoundRects();
	Serial.print(F("Rounded rects (outline)  "));
	Serial.println(usecRoundRects);
	delay(100);

	uint32_t usedFilledRoundRects = testFilledRoundRects();
	Serial.print(F("Rounded rects (filled)   "));
	Serial.println(usedFilledRoundRects);
	delay(100);

	Serial.println(F("Done!"));

	uint16_t c = 4;
	int8_t d = 1;
	for (int32_t i = 0; i < tft.height(); i++)
	{
		tft.drawFastHLine(0, i, tft.width(), c);
		c += d;
		if (c <= 4 || c >= 11)
			d = -d;
	}
	
	tft.setCursor(0, 0);
	tft.setTextColor(TFT_MAGENTA);
	tft.setTextSize(2);

 	tft.println(F("   TFT_eSPI test"));

	tft.setTextSize(1);
	tft.setTextColor(TFT_WHITE);
	tft.println(F(""));
	tft.setTextSize(1);
	tft.println(F(""));
	tft.setTextColor(tft.color565(0x80, 0x80, 0x80));

	tft.println(F(""));


	tft.setTextColor(TFT_GREEN);
	tft.println(F(" Benchmark               microseconds"));
	tft.println(F(""));
	tft.setTextColor(TFT_YELLOW);

	tft.setTextColor(TFT_CYAN); tft.setTextSize(1);
	tft.print(F("HaD pushColor      "));
	tft.setTextColor(TFT_YELLOW); tft.setTextSize(2);
	printnice(usecHaD);

	tft.setTextColor(TFT_CYAN); tft.setTextSize(1);
	tft.print(F("Screen fill        "));
	tft.setTextColor(TFT_YELLOW); tft.setTextSize(2);
	printnice(usecFillScreen);

	tft.setTextColor(TFT_CYAN); tft.setTextSize(1);
	tft.print(F("Text               "));
	tft.setTextColor(TFT_YELLOW); tft.setTextSize(2);
	printnice(usecText);

	tft.setTextColor(TFT_CYAN); tft.setTextSize(1);
	tft.print(F("Pixels             "));
	tft.setTextColor(TFT_YELLOW); tft.setTextSize(2);
	printnice(usecPixels);

	tft.setTextColor(TFT_CYAN); tft.setTextSize(1);
	tft.print(F("Lines              "));
	tft.setTextColor(TFT_YELLOW); tft.setTextSize(2);
	printnice(usecLines);

	tft.setTextColor(TFT_CYAN); tft.setTextSize(1);
	tft.print(F("Horiz/Vert Lines   "));
	tft.setTextColor(TFT_YELLOW); tft.setTextSize(2);
	printnice(usecFastLines);

	tft.setTextColor(TFT_CYAN); tft.setTextSize(1);
	tft.print(F("Rectangles         "));
	tft.setTextColor(TFT_YELLOW); tft.setTextSize(2);
	printnice(usecRects);

	tft.setTextColor(TFT_CYAN); tft.setTextSize(1);
	tft.print(F("Rectangles-filled  "));
	tft.setTextColor(TFT_YELLOW); tft.setTextSize(2);
	printnice(usecFilledRects);

	tft.setTextColor(TFT_CYAN); tft.setTextSize(1);
	tft.print(F("Circles            "));
	tft.setTextColor(TFT_YELLOW); tft.setTextSize(2);
	printnice(usecCircles);

	tft.setTextColor(TFT_CYAN); tft.setTextSize(1);
	tft.print(F("Circles-filled     "));
	tft.setTextColor(TFT_YELLOW); tft.setTextSize(2);
	printnice(usecFilledCircles);

	tft.setTextColor(TFT_CYAN); tft.setTextSize(1);
	tft.print(F("Triangles          "));
	tft.setTextColor(TFT_YELLOW); tft.setTextSize(2);
	printnice(usecTriangles);

	tft.setTextColor(TFT_CYAN); tft.setTextSize(1);
	tft.print(F("Triangles-filled   "));
	tft.setTextColor(TFT_YELLOW); tft.setTextSize(2);
	printnice(usecFilledTrangles);

	tft.setTextColor(TFT_CYAN); tft.setTextSize(1);
	tft.print(F("Rounded rects      "));
	tft.setTextColor(TFT_YELLOW); tft.setTextSize(2);
	printnice(usecRoundRects);

	tft.setTextColor(TFT_CYAN); tft.setTextSize(1);
	tft.print(F("Rounded rects-fill "));
	tft.setTextColor(TFT_YELLOW); tft.setTextSize(2);
	printnice(usedFilledRoundRects);

	tft.setTextSize(1);
	tft.println(F(""));
	tft.setTextColor(TFT_GREEN); tft.setTextSize(2);
	tft.print(F("Benchmark Complete!"));

	delay(60 * 1000L);
}

void printnice(int32_t v)
{
	char	str[32] = { 0 };
	sprintf(str, "%d", v);
	for (char *p = (str+strlen(str))-3; p > str; p -= 3)
	{
		memmove(p+1, p, strlen(p)+1);
		*p = ',';
		
	}
	while (strlen(str) < 10)
	{
		memmove(str+1, str, strlen(str)+1);
		*str = ' ';
	}
	tft.println(str);
}

static inline uint32_t micros_start() __attribute__ ((always_inline));
static inline uint32_t micros_start()
{
	uint8_t oms = millis();
	while ((uint8_t)millis() == oms)
		;
	return micros();
}

uint32_t testHaD()
{
	// pseudo-code for cheesy RLE
	// start with color1
	// while more input data remaining
	// 	count =  0nnnnnnn = 1 byte or 1nnnnnnn nnnnnnnn 2 bytes (0 - 32767)
	// 	repeat color count times
	// 	toggle color1/color2
	static const uint8_t HaD_240x320[] PROGMEM =
	{
		0xb9, 0x50, 0x0e, 0x80, 0x93, 0x0e, 0x41, 0x11, 0x80, 0x8d, 0x11, 0x42, 0x12, 0x80, 0x89, 0x12, 
		0x45, 0x12, 0x80, 0x85, 0x12, 0x48, 0x12, 0x80, 0x83, 0x12, 0x4a, 0x13, 0x7f, 0x13, 0x4c, 0x13, 
		0x7d, 0x13, 0x4e, 0x13, 0x7b, 0x13, 0x50, 0x13, 0x79, 0x13, 0x52, 0x13, 0x77, 0x13, 0x54, 0x13, 
		0x75, 0x13, 0x57, 0x11, 0x75, 0x11, 0x5a, 0x11, 0x73, 0x11, 0x5c, 0x11, 0x71, 0x11, 0x5e, 0x10, 
		0x71, 0x10, 0x60, 0x10, 0x6f, 0x10, 0x61, 0x10, 0x6f, 0x10, 0x60, 0x11, 0x6f, 0x11, 0x5e, 0x13, 
		0x6d, 0x13, 0x5c, 0x14, 0x6d, 0x14, 0x5a, 0x15, 0x6d, 0x15, 0x58, 0x17, 0x6b, 0x17, 0x37, 0x01, 
		0x1f, 0x17, 0x6b, 0x17, 0x1f, 0x01, 0x17, 0x02, 0x1d, 0x18, 0x6b, 0x18, 0x1d, 0x02, 0x17, 0x03, 
		0x1b, 0x19, 0x6b, 0x19, 0x1b, 0x03, 0x17, 0x05, 0x18, 0x1a, 0x6b, 0x1a, 0x18, 0x05, 0x17, 0x06, 
		0x16, 0x1b, 0x6b, 0x1b, 0x16, 0x06, 0x17, 0x07, 0x14, 0x1c, 0x6b, 0x1c, 0x14, 0x07, 0x17, 0x08, 
		0x12, 0x1d, 0x6b, 0x1d, 0x12, 0x08, 0x17, 0x09, 0x10, 0x1e, 0x6b, 0x1e, 0x10, 0x09, 0x17, 0x0a, 
		0x0e, 0x1f, 0x6b, 0x1f, 0x0e, 0x0a, 0x17, 0x0b, 0x0c, 0x20, 0x6b, 0x20, 0x0c, 0x0b, 0x17, 0x0c, 
		0x0b, 0x21, 0x69, 0x21, 0x0b, 0x0c, 0x18, 0x0d, 0x08, 0x23, 0x67, 0x23, 0x08, 0x0d, 0x19, 0x0e, 
		0x06, 0x26, 0x63, 0x26, 0x06, 0x0e, 0x19, 0x0f, 0x04, 0x28, 0x61, 0x28, 0x04, 0x0f, 0x19, 0x10, 
		0x02, 0x2a, 0x5f, 0x2a, 0x02, 0x10, 0x1a, 0x3c, 0x5d, 0x3c, 0x1b, 0x3d, 0x5b, 0x3d, 0x1c, 0x3d, 
		0x59, 0x3d, 0x1d, 0x3e, 0x57, 0x3e, 0x1e, 0x3e, 0x55, 0x3e, 0x1f, 0x40, 0x51, 0x40, 0x20, 0x40, 
		0x4f, 0x40, 0x22, 0x40, 0x22, 0x09, 0x22, 0x40, 0x24, 0x40, 0x1a, 0x17, 0x1a, 0x40, 0x26, 0x40, 
		0x16, 0x1d, 0x16, 0x40, 0x28, 0x40, 0x12, 0x23, 0x12, 0x40, 0x2a, 0x40, 0x0f, 0x27, 0x0f, 0x40, 
		0x2c, 0x41, 0x0b, 0x2b, 0x0b, 0x41, 0x2f, 0x3f, 0x09, 0x2f, 0x09, 0x3f, 0x32, 0x3d, 0x08, 0x33, 
		0x08, 0x3d, 0x35, 0x3a, 0x08, 0x35, 0x08, 0x3a, 0x3a, 0x36, 0x07, 0x39, 0x07, 0x36, 0x41, 0x09, 
		0x05, 0x23, 0x07, 0x3b, 0x07, 0x23, 0x05, 0x09, 0x54, 0x21, 0x07, 0x3d, 0x07, 0x21, 0x64, 0x1f, 
		0x06, 0x41, 0x06, 0x1f, 0x66, 0x1d, 0x06, 0x43, 0x06, 0x1d, 0x68, 0x1b, 0x06, 0x45, 0x06, 0x1b, 
		0x6b, 0x18, 0x06, 0x47, 0x06, 0x18, 0x6e, 0x16, 0x06, 0x49, 0x06, 0x16, 0x70, 0x14, 0x06, 0x4b, 
		0x06, 0x14, 0x72, 0x13, 0x06, 0x4b, 0x06, 0x13, 0x74, 0x11, 0x06, 0x4d, 0x06, 0x11, 0x76, 0x0f, 
		0x06, 0x4f, 0x06, 0x0f, 0x78, 0x0e, 0x05, 0x51, 0x05, 0x0e, 0x7a, 0x0c, 0x06, 0x51, 0x06, 0x0c, 
		0x7d, 0x09, 0x06, 0x53, 0x06, 0x09, 0x80, 0x80, 0x08, 0x05, 0x55, 0x05, 0x08, 0x80, 0x82, 0x06, 
		0x05, 0x57, 0x05, 0x06, 0x80, 0x84, 0x05, 0x05, 0x57, 0x05, 0x05, 0x80, 0x86, 0x03, 0x05, 0x59, 
		0x05, 0x03, 0x80, 0x88, 0x02, 0x05, 0x59, 0x05, 0x02, 0x80, 0x8f, 0x5b, 0x80, 0x95, 0x5b, 0x80, 
		0x94, 0x5d, 0x80, 0x93, 0x5d, 0x80, 0x92, 0x5e, 0x80, 0x92, 0x5f, 0x80, 0x91, 0x5f, 0x80, 0x90, 
		0x61, 0x80, 0x8f, 0x61, 0x80, 0x8f, 0x61, 0x80, 0x8e, 0x63, 0x80, 0x8d, 0x63, 0x80, 0x8d, 0x63, 
		0x80, 0x8d, 0x63, 0x80, 0x8c, 0x19, 0x07, 0x25, 0x07, 0x19, 0x80, 0x8b, 0x16, 0x0d, 0x1f, 0x0d, 
		0x16, 0x80, 0x8b, 0x14, 0x11, 0x1b, 0x11, 0x14, 0x80, 0x8b, 0x13, 0x13, 0x19, 0x13, 0x13, 0x80, 
		0x8b, 0x12, 0x15, 0x17, 0x15, 0x12, 0x80, 0x8a, 0x12, 0x17, 0x15, 0x17, 0x12, 0x80, 0x89, 0x11, 
		0x19, 0x13, 0x19, 0x11, 0x80, 0x89, 0x11, 0x19, 0x13, 0x19, 0x11, 0x80, 0x89, 0x10, 0x1b, 0x11, 
		0x1b, 0x10, 0x80, 0x89, 0x0f, 0x1c, 0x11, 0x1c, 0x0f, 0x80, 0x89, 0x0f, 0x1c, 0x11, 0x1c, 0x0f, 
		0x80, 0x89, 0x0f, 0x1c, 0x11, 0x1c, 0x0f, 0x80, 0x89, 0x0e, 0x1d, 0x11, 0x1d, 0x0e, 0x80, 0x89, 
		0x0e, 0x1c, 0x13, 0x1c, 0x0e, 0x80, 0x89, 0x0e, 0x1b, 0x15, 0x1b, 0x0e, 0x80, 0x89, 0x0e, 0x1b, 
		0x15, 0x1b, 0x0e, 0x80, 0x89, 0x0e, 0x1a, 0x17, 0x1a, 0x0e, 0x80, 0x89, 0x0e, 0x18, 0x1b, 0x18, 
		0x0e, 0x80, 0x89, 0x0e, 0x16, 0x1f, 0x16, 0x0e, 0x80, 0x89, 0x0e, 0x14, 0x23, 0x14, 0x0e, 0x80, 
		0x89, 0x0f, 0x11, 0x27, 0x11, 0x0f, 0x80, 0x89, 0x0f, 0x0e, 0x2d, 0x0e, 0x0f, 0x80, 0x89, 0x0f, 
		0x0c, 0x31, 0x0c, 0x0f, 0x80, 0x89, 0x0f, 0x0b, 0x33, 0x0b, 0x0f, 0x80, 0x8a, 0x0f, 0x09, 0x35, 
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
	};
	
	tft.fillScreen(TFT_BLACK);

	uint32_t start = micros_start();

	for (int i = 0; i < 0x10; i++)
	{
		tft.setAddrWindow(0, 0, 240, 320);

		uint16_t cnt = 0;
		uint16_t color = tft.color565((i << 4) | i, (i << 4) | i, (i << 4) | i);
		uint16_t curcolor = 0;

		const uint8_t *cmp = &HaD_240x320[0];

		tft.startWrite();
		while (cmp < &HaD_240x320[sizeof(HaD_240x320)])
		{
			cnt = pgm_read_byte(cmp++);
			if (cnt & 0x80) cnt = ((cnt & 0x7f) << 8) | pgm_read_byte(cmp++);
			tft.pushColor(curcolor, cnt);	// PDQ_GFX has count
			curcolor ^= color;
		}
		tft.endWrite();
	}

	uint32_t t = micros() - start;

	tft.setTextColor(TFT_YELLOW);
	tft.setTextSize(2);
	tft.setCursor(8, 285);
	tft.print(F("http://hackaday.io/"));
	tft.setCursor(96, 302);
	tft.print(F("Xark"));

	delay(3 * 1000L);
	
	return t;
}

uint32_t testFillScreen()
{
	uint32_t start = micros_start();
    // Shortened this tedious test!
		tft.fillScreen(TFT_WHITE);
		tft.fillScreen(TFT_RED);
		tft.fillScreen(TFT_GREEN);
		tft.fillScreen(TFT_BLUE);
		tft.fillScreen(TFT_BLACK);

	return (micros() - start)/5;
}

uint32_t testText()
{
	tft.fillScreen(TFT_BLACK);
	uint32_t start = micros_start();
	tft.setCursor(0, 0);
	tft.setTextColor(TFT_WHITE,TFT_BLACK);	tft.setTextSize(1);
	tft.println(F("Hello World!"));
	tft.setTextSize(2);
	tft.setTextColor(tft.color565(0xff, 0x00, 0x00));
	tft.print(F("RED "));
	tft.setTextColor(tft.color565(0x00, 0xff, 0x00));
	tft.print(F("GREEN "));
	tft.setTextColor(tft.color565(0x00, 0x00, 0xff));
	tft.println(F("BLUE"));
	tft.setTextColor(TFT_YELLOW); tft.setTextSize(2);
	tft.println(1234.56);
	tft.setTextColor(TFT_RED);		tft.setTextSize(3);
	tft.println(0xDEADBEEF, HEX);
	tft.println();
	tft.setTextColor(TFT_GREEN);
	tft.setTextSize(5);
	tft.println(F("Groop"));
	tft.setTextSize(2);
	tft.println(F("I implore thee,"));
  tft.setTextColor(TFT_GREEN);
	tft.setTextSize(1);
	tft.println(F("my foonting turlingdromes."));
	tft.println(F("And hooptiously drangle me"));
	tft.println(F("with crinkly bindlewurdles,"));
	tft.println(F("Or I will rend thee"));
	tft.println(F("in the gobberwarts"));
	tft.println(F("with my blurglecruncheon,"));
	tft.println(F("see if I don't!"));
	tft.println(F(""));
	tft.println(F(""));
	tft.setTextColor(TFT_MAGENTA);
	tft.setTextSize(6);
	tft.println(F("Woot!"));
	uint32_t t = micros() - start;
	delay(1000);
	return t;
}

uint32_t testPixels()
{
	int32_t	w = tft.width();
	int32_t	h = tft.height();

	uint32_t start = micros_start();
	tft.startWrite();
	for (uint16_t y = 0; y < h; y++)
	{
		for (uint16_t x = 0; x < w; x++)
		{
			tft.drawPixel(x, y, tft.color565(x<<3, y<<3, x*y));
		}
	}
	tft.endWrite();
	return micros() - start;
}


uint32_t testLines(uint16_t color)
{
	uint32_t start, t;
	int32_t	x1, y1, x2, y2;
	int32_t	w = tft.width();
	int32_t	h = tft.height();

	tft.fillScreen(TFT_BLACK);

	x1 = y1 = 0;
	y2 = h - 1;

	start = micros_start();

	for (x2 = 0; x2 < w; x2 += 6)
	{
		tft.drawLine(x1, y1, x2, y2, color);
	}

	x2 = w - 1;

	for (y2 = 0; y2 < h; y2 += 6)
	{
		tft.drawLine(x1, y1, x2, y2, color);
	}

	t = micros() - start; // fillScreen doesn't count against timing

	tft.fillScreen(TFT_BLACK);

	x1 = w - 1;
	y1 = 0;
	y2 = h - 1;

	start = micros_start();

	for (x2 = 0; x2 < w; x2 += 6)
	{
		tft.drawLine(x1, y1, x2, y2, color);
	}

	x2 = 0;
	for (y2 = 0; y2 < h; y2 += 6)
	{
		tft.drawLine(x1, y1, x2, y2, color);
	}

	t += micros() - start;

	tft.fillScreen(TFT_BLACK);

	x1 = 0;
	y1 = h - 1;
	y2 = 0;

	start = micros_start();

	for (x2 = 0; x2 < w; x2 += 6)
	{
		tft.drawLine(x1, y1, x2, y2, color);
	}
	x2 = w - 1;
	for (y2 = 0; y2 < h; y2 += 6)
	{
		tft.drawLine(x1, y1, x2, y2, color);
	}
	t += micros() - start;

	tft.fillScreen(TFT_BLACK);

	x1 = w - 1;
	y1 = h - 1;
	y2 = 0;

	start = micros_start();

	for (x2 = 0; x2 < w; x2 += 6)
	{
		tft.drawLine(x1, y1, x2, y2, color);
	}

	x2 = 0;
	for (y2 = 0; y2 < h; y2 += 6)
	{
		tft.drawLine(x1, y1, x2, y2, color);
	}

	t += micros() - start;

	return t;
}

uint32_t testFastLines(uint16_t color1, uint16_t color2)
{
	uint32_t start;
	int32_t x, y;
	int32_t w = tft.width();
	int32_t h = tft.height();

	tft.fillScreen(TFT_BLACK);

	start = micros_start();

	for (y = 0; y < h; y += 5)
		tft.drawFastHLine(0, y, w, color1);
	for (x = 0; x < w; x += 5)
		tft.drawFastVLine(x, 0, h, color2);

	return micros() - start;
}

uint32_t testRects(uint16_t color)
{
	uint32_t start;
	int32_t n, i, i2;
	int32_t cx = tft.width() / 2;
	int32_t cy = tft.height() / 2;

	tft.fillScreen(TFT_BLACK);
	n = min(tft.width(), tft.height());
	start = micros_start();
	for (i = 2; i < n; i += 6)
	{
		i2 = i / 2;
		tft.drawRect(cx-i2, cy-i2, i, i, color);
	}

	return micros() - start;
}

uint32_t testFilledRects(uint16_t color1, uint16_t color2)
{
	uint32_t start, t = 0;
	int32_t n, i, i2;
	int32_t cx = tft.width() / 2 - 1;
	int32_t cy = tft.height() / 2 - 1;

	tft.fillScreen(TFT_BLACK);
	n = min(tft.width(), tft.height());
	for (i = n; i > 0; i -= 6)
	{
		i2 = i / 2;

		start = micros_start();

		tft.fillRect(cx-i2, cy-i2, i, i, color1);

		t += micros() - start;

		// Outlines are not included in timing results
		tft.drawRect(cx-i2, cy-i2, i, i, color2);
	}

	return t;
}

uint32_t testFilledCircles(uint8_t radius, uint16_t color)
{
	uint32_t start;
	int32_t x, y, w = tft.width(), h = tft.height(), r2 = radius * 2;

	tft.fillScreen(TFT_BLACK);

	start = micros_start();

	for (x = radius; x < w; x += r2)
	{
		for (y = radius; y < h; y += r2)
		{
			tft.fillCircle(x, y, radius, color);
		}
	}

	return micros() - start;
}

uint32_t testCircles(uint8_t radius, uint16_t color)
{
	uint32_t start;
	int32_t x, y, r2 = radius * 2;
	int32_t w = tft.width() + radius;
	int32_t h = tft.height() + radius;

	// Screen is not cleared for this one -- this is
	// intentional and does not affect the reported time.
	start = micros_start();

	for (x = 0; x < w; x += r2)
	{
		for (y = 0; y < h; y += r2)
		{
			tft.drawCircle(x, y, radius, color);
		}
	}

	return micros() - start;
}

uint32_t testTriangles()
{
	uint32_t start;
	int32_t n, i;
	int32_t cx = tft.width()/ 2 - 1;
	int32_t cy = tft.height() / 2 - 1;

	tft.fillScreen(TFT_BLACK);
	n = min(cx, cy);

	start = micros_start();

	for (i = 0; i < n; i += 5)
	{
		tft.drawTriangle(
			cx		, cy - i, // peak
			cx - i, cy + i, // bottom left
			cx + i, cy + i, // bottom right
			tft.color565(0, 0, i));
	}

	return micros() - start;
}

uint32_t testFilledTriangles()
{
	uint32_t start, t = 0;
	int32_t i;
	int32_t cx = tft.width() / 2 - 1;
	int32_t cy = tft.height() / 2 - 1;

	tft.fillScreen(TFT_BLACK);

	start = micros_start();

	for (i = min(cx,cy); i > 10; i -= 5) {
		start = micros_start();
		tft.fillTriangle(cx, cy - i, cx - i, cy + i, cx + i, cy + i,
			tft.color565(0, i, i));
		t += micros() - start;
		tft.drawTriangle(cx, cy - i, cx - i, cy + i, cx + i, cy + i,
			tft.color565(i, i, 0));
	}

	return t;
}

uint32_t testRoundRects()
 {
	uint32_t start;
	int32_t w, i, i2;
	int32_t cx = tft.width() / 2 - 1;
	int32_t cy = tft.height() / 2 - 1;

	tft.fillScreen(TFT_BLACK);
	
	w = min(tft.width(), tft.height());
	
	start = micros_start();

	for (i = 0; i < w; i += 6)
	{
		i2 = i / 2;
		tft.drawRoundRect(cx-i2, cy-i2, i, i, i/8, tft.color565(i, 0, 0));
	}

	return micros() - start;
}

uint32_t testFilledRoundRects()
{
	uint32_t start;
	int32_t i, i2;
	int32_t cx = tft.width() / 2 - 1;
	int32_t cy = tft.height() / 2 - 1;

	tft.fillScreen(TFT_BLACK);

	start = micros_start();

	for (i = min(tft.width(), tft.height()); i > 20; i -= 6)
	{
		i2 = i / 2;
		tft.fillRoundRect(cx-i2, cy-i2, i, i, i/8, tft.color565(0, i, 0));
	}

	return micros() - start;
}

/***************************************************
  Original sketch text:

  This is an example sketch for the Adafruit 2.2" SPI display.
  This library works with the Adafruit 2.2" TFT Breakout w/SD card
  ----> http://www.adafruit.com/products/1480
 
  Check out the links above for our tutorials and wiring diagrams
  These displays use SPI to communicate, 4 or 5 pins are required to
  interface (RST is optional)
  Adafruit invests time and resources providing this open source code,
  please support Adafruit and open-source hardware by purchasing
  products from Adafruit!

  Written by Limor Fried/Ladyada for Adafruit Industries.
  MIT license, all text above must be included in any redistribution
 ****************************************************/
 

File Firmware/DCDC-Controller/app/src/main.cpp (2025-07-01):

#include <stdio.h>
#include <zephyr/kernel.h>
#include <zephyr/drivers/gpio.h>
#include <zephyr/drivers/charger.h>

#include "util.h"
#include "../../packages/BQ2575x/drivers/charger/bq2575x.h"

/* 1000 msec = 1 sec */
#define SLEEP_TIME_MS   500

/* The devicetree node identifier for the "led0" alias. */
#define LED0_NODE DT_ALIAS(led0)

/*
 * A build error on this line means your board is unsupported.
 * See the sample documentation for information on how to fix this.
 */
static const struct gpio_dt_spec led = GPIO_DT_SPEC_GET(LED0_NODE, gpios);

static const struct gpio_dt_spec dcdc_en_ = GPIO_DT_SPEC_GET(DT_NODELABEL(dcdc_en), gpios);

const struct device *dcdc = DEVICE_DT_GET(DT_NODELABEL(bq2575x));

void i2c_scan(void);
void i2c_dump(uint16_t addr, uint8_t regStart, uint8_t regStop);

BQ2575x *bq;

int main(void)
{
	int ret;
	bool led_state = true;

	gpio_pin_configure_dt(&dcdc_en_, GPIO_OUTPUT_INACTIVE);

	if (device_is_ready(dcdc)) {
		charger_propval val;
		val.const_charge_voltage_uv = 9000e3;
		charger_set_prop(dcdc, CHARGER_PROP_CONSTANT_CHARGE_VOLTAGE_UV, &val);
		val.input_current_regulation_current_ua = 5000e3;
		charger_set_prop(dcdc, CHARGER_PROP_INPUT_REGULATION_CURRENT_UA, &val);

		charger_get_prop(dcdc, CHARGER_PROP_CONSTANT_CHARGE_VOLTAGE_UV, &val);
		printf("CC uV: %d\n", val.const_charge_voltage_uv);
		charger_get_prop(dcdc, CHARGER_PROP_CONSTANT_CHARGE_CURRENT_UA, &val);
		printf("CC uA: %d\n", val.const_charge_current_ua);
		charger_get_prop(dcdc, CHARGER_PROP_INPUT_REGULATION_CURRENT_UA, &val);
		printf("IC uA: %d\n", val.input_current_regulation_current_ua);

		// charger_get_prop(dcdc, CHARGER_PROP_BQ_INST, &val);
		// bq = (BQ2575x*)val.system_voltage_notification;
		// bq->setValue<BQ2575x::adc

		gpio_pin_set_dt(&dcdc_en_, 1);
	}

	if (!gpio_is_ready_dt(&led)) {
		return 0;
	}

	ret = gpio_pin_configure_dt(&led, GPIO_OUTPUT_ACTIVE);
	if (ret < 0) {
		return 0;
	}

	while (1) {
		ret = gpio_pin_toggle_dt(&led);
		if (ret < 0) {
			return 0;
		}


		led_state = !led_state;
		// printf("LED state: %s\n", led_state ? "ON" : "OFF");
		k_msleep(SLEEP_TIME_MS);

		// This makes the DCDC not turn on properly? WTF (works until this code block gets executed??)
		// uint8_t buf[1];
		// const uint8_t startAddr = 0x21;
		// i2c_write_read(dcdc, 0x6B, &startAddr, 1, buf, sizeof(buf));
		// printf("Status: %02X %02X %02X %02X\n", buf[0], buf[1], buf[2], buf[3]);

		// i2c_scan();
		i2c_dump(0x6B, 0, 0x3F);

	}
	return 0;
}

// I2C scan code from: https://github.com/iFransL/i2c-scanner
#include <zephyr/sys/printk.h>
#include <zephyr/drivers/i2c.h>

#define CONFIG_I2C_SCAN_ADDR_START 8
#define CONFIG_I2C_SCAN_ADDR_STOP  127

/* Check if devicetree node identifier with the alias "my-i2c" is defined						*/
/* If not defined use the default defined node for the arduino_i2c pins on the development kit 	*/
#if DT_NODE_HAS_STATUS(DT_ALIAS(my_i2c), okay)
	#define I2C_NODE DT_ALIAS(my_i2c)
	#define I2C_DEV	DT_PROP(I2C_NODE, label)
#else
	#define I2C_NODE DT_NODELABEL(arduino_i2c)
	#if DT_NODE_HAS_STATUS(I2C_NODE, okay)
		#define I2C_DEV	DT_PROP(I2C_NODE, label)
	#else
		#error "Arduino_i2c not defined, specify the I2C bus to use with the alias "my-i2c""
		#define I2C_DEV ""
	#endif
#endif

void i2c_scan(void)
{
	const struct device *i2c_dev;

	k_sleep(K_SECONDS(1));
	printf("*** I2C scanner started.                    ***\nBoard name      : %s\n", CONFIG_BOARD);

	// i2c_dev = device_get_binding(I2C_DEV);
	// 	if (!i2c_dev) {
	// 	printf("I2C: Device driver not found.\n");
	// 	return;
	// }

	i2c_dev = DEVICE_DT_GET(DT_NODELABEL(gpio_i2c0));

	printf("I2C Port        : %s \n",I2C_DEV);
	printf("Clock Frequency : %d \n",DT_PROP(I2C_NODE, clock_frequency));

#ifndef CONFIG_PINCTRL_NRF
	// From NCS2.0.0 pin-control is used, not possible to read out the used pins from I2C_NODE 
	// printf("SDA-PIN         : %d \n",DT_PROP(I2C_NODE, sda_pin));
	// printf("SCL-PIN         : %d \n",DT_PROP(I2C_NODE, scl_pin));
#endif

	printf("\n    | 0x00 0x01 0x02 0x03 0x04 0x05 0x06 0x07 0x08 0x09 0x0a 0x0b 0x0c 0x0d 0x0e 0x0f |\n");
	printf(  "----|---------------------------------------------------------------------------------");
	
	uint8_t error = 0u;
	uint8_t dst;
	uint8_t i2c_dev_cnt = 0;
	struct i2c_msg msgs[1];
	msgs[0].buf = &dst;
	msgs[0].len = 1U;
	msgs[0].flags = I2C_MSG_WRITE | I2C_MSG_STOP;

	/* Use the full range of I2C address for display purpose */	
	for (uint16_t x = 0; x <= 0x7f; x++) {
		/* New line every 0x10 address */
		if (x % 0x10 == 0) {
			printf("|\n0x%02x| ",x);	
		}
		/* Range the test with the start and stop value configured in the kconfig */
		if (x >= CONFIG_I2C_SCAN_ADDR_START && x <= CONFIG_I2C_SCAN_ADDR_STOP)	{	
			/* Send the address to read from */
			error = i2c_transfer(i2c_dev, &msgs[0], 1, x);
				/* I2C device found on current address */
				if (error == 0) {
					printf("0x%02x ",x);
					i2c_dev_cnt++;
				}
				else {
					printf(" --  ");
				}
		} else {
			/* Scan value out of range, not scanned */
			printf("     ");
		}
	}
	printf("|\n");
	printf("\nI2C device(s) found on the bus: %d\nScanning done.\n\n", i2c_dev_cnt);
	printf("Find the registered I2C address on: https://i2cdevices.org/addresses\n\n");
}


void i2c_dump(uint16_t addr, uint8_t regStart, uint8_t regStop) {
	uint8_t buf[regStop - regStart + 1] = {0};
	const struct device *i2c_dev;
	i2c_dev = DEVICE_DT_GET(DT_NODELABEL(gpio_i2c0));

	uint8_t dst;
	struct i2c_msg msg = {
		.buf = &dst,
		.len = 1,
		.flags = I2C_MSG_READ | I2C_MSG_STOP,
	};

	i2c_write_read(i2c_dev, addr, &regStart, 1, buf, sizeof(buf));

	printHex(buf, sizeof(buf));
}

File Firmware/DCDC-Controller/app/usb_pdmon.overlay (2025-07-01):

#include <dt-bindings/usb-c/pd.h>

/ {

    chosen {
        zephyr,console = &usart1;
    };
/*
    pwmleds {
		compatible = "pwm-leds";
		pwm_ctl: g0 {
			pwms = <&pwm2 0 PWM_USEC(50) PWM_POLARITY_INVERTED>;
			label = "PWM CTL";
		};
	};*/

	
    leds {
        compatible = "gpio-leds";
        led_r:   led_r   { gpios = <&gpioa 0 GPIO_ACTIVE_LOW>;  };
        led_g:   led_g   { gpios = <&gpioa 1 GPIO_ACTIVE_LOW>;  };
        led_b:   led_b   { gpios = <&gpioa 2 GPIO_ACTIVE_LOW>;  };
	};

	aliases {
		usbc-port0 = &port1;
		my-i2c = &gpio_i2c0;
	};

    pwrctrl {
		compatible = "gpio-leds";

		dcdc_en: dcdc_en {
			gpios = <&gpiob 0 GPIO_ACTIVE_LOW>;
			label = "V_CTL2";
		};

		vconn1_en: vconn1_en {
			gpios = <&gpiob 6 GPIO_ACTIVE_HIGH>;
			label = "VCONN1_EN";
		};

		vconn2_en: vconn2_en {
			gpios = <&gpiob 7 GPIO_ACTIVE_HIGH>;
			label = "VCONN2_EN";
		};
	};

	gpio_i2c0: gpio_i2c0 {                                                                                         
		compatible = "gpio-i2c-emod";
		status = "okay";
		clock-frequency = <400000>;
		sda-gpios = <&gpiob 4 GPIO_ACTIVE_HIGH>;
		scl-gpios = <&gpiob 3 GPIO_ACTIVE_HIGH>;
		label = "GPIO_I2C_0";
		#address-cells = <1>;
		#size-cells = <0>;

		bq2575x: charger@6B {
			compatible = "ti,bq2575x";
			reg = <0x6B>;
			status = "okay";
		};
	};


};

&port1 {
	power-role = "source";
	data-role = "dual"; /* actually means disconnected */
	typec-power-opmode = "1.5A";
	source-pdos = <PDO_FIXED(5000, 100, 0) 
		PDO_FIXED(9000, 100, 0) 
		PDO_FIXED(20000, 5000, 0) 
		PDO_FIXED(48000, 100, 0) 
		PDO_PPS_APDO(3300, 48000, 5000)>;
};

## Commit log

2025-02-01 add current state (Schematic done-ish, parts placement done-ish, next up: traces)
    [CC_Protect.kicad_sch, DCDC.kicad_sch, ER-TFT1.47A1 ST7789 5mm-high bent -1.5mm.step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]
2025-02-03 final tweaks before routing traces
    [DCDC.kicad_sch, UI.kicad_sch, USB-C PSU.kicad_pcb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]
2025-02-03 main power layout almost done
    UI board and details still left to do
    [DCDC.kicad_sch, USB-C PSU.kicad_pcb]
2025-02-03 UI layout done
    [DCDC.kicad_sch, UI.kicad_sch, USB-C PSU.kicad_pcb]
2025-02-06 oops, all vias
    [DCDC.kicad_sch, USB-C PSU.kicad_pcb, USB-C PSU.kicad_sch]
2025-02-10 design silkscreen markings + some polish
    [DCDC.kicad_sch, USB-C PSU.kicad_pcb, USB-C PSU.kicad_sch]
2025-02-13 final tweaks for v1.0
    [BOM-USB-C PSU.csv, UI.kicad_sch, USB-C PSU LCSC ToBuy.csv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]
2025-02-14 add documentation
    [ER-TFT1.47A1-1.STEP]
2025-02-26 try creating a zephyr project
    currently borked
2025-06-28 [BQ] copy files from zephyr i2c gpio driver
2025-06-28 implement open drain emulation for gpio-i2c
2025-06-28 [BQ] add changes from around april
    (it compiles, but doesn't do very much as of right now)
    [bq2575x.cpp]
2025-06-30 [BQ] test: dump I2C registers
2025-07-01 [BQ] basic DCDC control working, it's switching for the first time!
